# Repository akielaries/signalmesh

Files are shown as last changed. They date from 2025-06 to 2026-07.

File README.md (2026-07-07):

# signalmesh
*signalmesh* is a hybrid analog/digital synthesizer. For now it is a mess of reworked PCBs, perf/breadboards, and wires on my desk.

CAD work going on here right now: https://github.com/akielaries/signalmesh_CAD/

# Details
Don't forget to initialize submodules. ChibiOS is the RTOS used in this project on an STM32H7. I'm mostly building around an H755, 
occasionally the H753 but the H745/743 will probably work as well. AFAIK the only difference is the additional ARM M4 core and some
crypo acceleration stuff.

```
git submodule init
git submodule update
```

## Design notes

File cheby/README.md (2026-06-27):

# Cheby
These are the cheby definitions for the memory mapped address space between the
ACM (Gowin FPGA) and the APM (STM32H755)

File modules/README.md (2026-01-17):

# Modules
These are the main board components of the `signalmesh` project

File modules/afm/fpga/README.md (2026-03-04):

# Cortex M1 example
Makes use of the Tang Mega 60k and the ARM Cortex M1 softcore. It makes use of the
gwct debug module from here: https://github.com/akielaries/gwct/tree/main

Uses:
- UART1
- APB1
- DDR3
- GPIO
- SWD

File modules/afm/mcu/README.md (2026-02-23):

# Audio FX Module
The idea here is:
- To have a bunch of parallel processing in RTL on the FPGA for filters and FX
- Audio data delivery over some physical medium. ATM I'm thinking I2S
- Cortex M1 MCU  handling control via AHB registers

This project uses a Gowin GW5AST FPGA on the Tang Mega 60k and the ARM Cortex M1
softcore IP provided by Gowin. Note that any of the Gowin supported FPGAs can be
used. I used the Gowin IDE to configure all settings

# Requirements
- A Gowin supported FPGA with the ARM Cortex M1 softcore configured with:
    - UART1
    - GPIO
    - Debug (Serial Wire)
- `arm-none-eabi-gcc` toolchain
- `gdb-multiarch`
- CMake

# How to build
From the root directory:
```
cmake -S . -B build/
cmake --build build/
```
and that will produce the compile ELF under build/bin/softcore_fw_example.elf.

To load the firmware:
```
gdb-multiarch build/bin/softcore_fw_example.elf

# connect to your debugger
(gdb) target extended-remote /dev/serial/by-id/usb-Black_Magic_Debug_Black_Magic_Probe__ST-Link_v2__v2.0.0-323-gf3b99649-dirty_8A8243AE-if00
Remote debugging using /dev/serial/by-id/usb-Black_Magic_Debug_Black_Magic_Probe__ST-Link_v2__v2.0.0-323-gf3b99649-dirty_8A8243AE-if00

# scan for available SWD targets
(gdb) mon swd
Target voltage: 0.48V
Available Targets:
No. Att Driver
 1      Generic Cortex-M1 M1

# attach, load, start
(gdb) att 1
Attaching to program: /home/akiel/GMD_workspace/softcore_fw_example/build/bin/softcore_fw_example.elf, Remote target
⚠️ warning: while parsing target memory map (at line 1): Required element <memory> is missing
delay_ms (nms=50) at /home/akiel/GMD_workspace/softcore_fw_example/src/delay.c:89
89			while((temp & 0x01) && !(temp & (1 << 16)));
(gdb) load
Loading section .text, size 0x1cb4 lma 0x0
Loading section .ARM.extab, size 0x3c lma 0x1cb4
Loading section .ARM.exidx, size 0xd8 lma 0x1cf0
Loading section .data, size 0x10 lma 0x1dc8
Start address 0x000001cc, load size 7640
Transfer rate: 84 KB/sec, 694 bytes/write.
(gdb) c
Continuing.
```

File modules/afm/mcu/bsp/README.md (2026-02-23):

# Board Support Package
This code comes from the Gowin MCU Designer (GMD) tool and remains unmodified
except for the linker and startup ASM files...

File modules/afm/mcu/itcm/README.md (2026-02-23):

# Initialized ITCM
This is just the initialized ITCM (instruction tightly coupled memory)
when the Cortex M1 softcore is configured in the IP menu. In this case it just prints the uptime
in seconds and blinks some LEDs via the "RTOS" this project uses...

# Build
This initialized ITCM code is built with the same cmake invocation as the top level application

# Generate ITCM files
I'm sure this could be reverse engineered into a proper linux program but to run the Gowin
make hex util I wrap up the following in a shell script called `gowin_make_hex`:

```
#!/bin/bash

# make_hex.exe executable
MAKE_HEX_EXE="Gowin_EMPU_M1_V2.3/tool/make_hex/bin/make_hex.exe"

wine "$MAKE_HEX_EXE" "$@"
```

```
gowin_make_hex ../../build/bootloader/bin/bootloader.bin
```

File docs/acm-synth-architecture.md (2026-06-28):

# ACM Synth - Architecture

The Audio Creation Module (ACM) is a hardware polyphonic synthesizer split across
two chips:

- a **STM32H755** (Nucleo-144) as the control + I/O manager - it hosts the USB-MIDI
  keyboard, allocates voices, and streams audio out its DAC.
- an **FPGA** (Tang Nano 20K / GW2AR-18, with a Tang Primer 25K / GW5A-25 as a
  second target) as the DSP - it runs the oscillator bank that actually makes sound.

They talk over a 16-bit multiplexed **FMC** bus, with the register interface defined
once in **Cheby** and generated for both sides. The whole signal chain, top to bottom:

ACM system architecture

<sub>Diagram source: `docs/diagrams/acm-architecture.dot` - render with
`dot -Tsvg acm-architecture.dot -o acm-architecture.svg`.</sub>

## Who does what

The guiding split: the **STM32 decides what to play, the FPGA makes the sound.**
After setup, the audio samples never pass through the CPU.

| Concern | STM32H755 | FPGA |
| --- | --- | --- |
| USB-MIDI host + note parsing | yes | - |
| Voice allocation (note -> voice) | yes | - |
| Note -> pitch (tuning word) | yes | - |
| Oscillators / waveforms | - | yes (dds_synth) |
| Mixing | - | yes |
| Sample -> DAC format | - | yes (dac reg) |
| Sample streaming to DAC | DMA only (no CPU) | - |

## End-to-end: a key becomes sound

The two halves run independently - the STM32 only touches registers on note
events, the FPGA free-runs at the sample rate, and the DMA bridges them at Fs:

```mermaid
flowchart TD
    A["key pressed: note-on (note, vel)"] --> B["STM32: allocate a free voice"]
    B --> C["STM32: write voice freq + gate + level (FMC)"]
    C --> D["FPGA free-runs: phase, wave, level, mix 8 -> dac reg"]
    D --> E["TIM6 DMA: dac reg -> DAC every 48 kHz tick"]
    E --> F["key released: note-off -> clear that voice gate"]
```

## FMC register map

One flat FMC address space, decoded on the FPGA by word-address bit 6
(`core` low, `audio` high). All registers are 16-bit (the audio `freq` is 32-bit
across two words).

| FMC byte | block.register | access | meaning |
| --- | --- | --- | --- |
| 0x00 | core.magic | RO | link check, reads 0xACE1 |
| 0x02 | core.fpga_id | RO | board id (0x2018 = 20K, 0x5025 = 25K) |
| 0x04 | core.scratch | RW | scratch / LED debug |
| 0x06 | core.version | RO | gateware version |
| 0x80 | audio.ctrl | RW | engine enable, sample-rate select |
| 0x82 | audio.status | RO | active voice count |
| 0x84 | audio.sample | RO | latest mixed sample, signed (debug) |
| 0x86 | audio.dac | RO | DAC-ready 12-bit code (DMA source) |
| 0xC0 + n*8 | audio.voice[n].freq | RW | 32-bit DDS tuning word |
| 0xC4 + n*8 | audio.voice[n].ctrl | RW | gate (b0), wave (b3:1), level (b15:8) |

> Gotcha: Cheby lays a 32-bit register **big-endian** over the 16-bit bus - the
> low word address holds bits [31:16]. Matters when the STM32 writes `freq`.

## Single source of truth: Cheby

The register layout is written once as YAML and generated for both sides, so the
firmware and the gateware can never disagree on the contract.

```mermaid
flowchart TD
    Y["*.yaml (core, audio)"] --> GEN["cheby/gen.sh"]
    GEN --> OUT["C headers (STM32) + verilog (FPGA)"]
```

- `bus: wb-16` - Wishbone, 16-bit, matched to the FMC so one FMC access = one bus
  cycle, no width adapter.
- RO registers become HDL **input ports** (the design drives them, e.g. per-board
  `fpga_id`); RW registers become stored regs.

## FPGA internals

`acm_top` is a pure-wiring composition root: the FMC bridge feeds an address
decode that splits into the two register files; the audio voice registers drive
the oscillator bank, whose mixed output is converted to a DAC-ready code.
(The Fs tick divider clocks the DDS; `audio.sample` is a signed debug tap.)

```mermaid
flowchart TD
    FMC["FMC bus"] --> BR["fmc_wb_bridge"]
    BR --> DEC{"decode wb_adr[6]"}
    DEC -->|"0"| CORE["core regs"]
    DEC -->|"1"| AUDIO["audio regs"]
    AUDIO --> DDS["dds_synth 8 voices + mix"]
    DDS --> CONV[">>3 +2048, clamp"]
    CONV --> DACREG["dac reg (12-bit)"]
```

### A DDS voice

Each of the 8 voices is a numerically-controlled oscillator (the bank is
time-multiplexed: one shared sine LUT + one multiplier walk the voices each tick).
The per-voice registers `freq`, `wave`, `level`, `gate` drive each stage below:

```mermaid
flowchart TD
    ACC["phase accumulator (+= freq)"] --> SEL["select waveform (wave)"]
    SEL --> SCALE["scale by level"]
    SCALE --> GATE["apply gate"]
    GATE --> MIX["sum 8 voices / 8"]
```

- `freq` (tuning word) sets pitch: `inc = note_freq * 2^32 / Fs`, accumulated each
  sample. The STM32 builds a 128-entry MIDI-note -> tuning-word table.
- `wave` selects sine (LUT) / saw / square / triangle.
- `level` scales amplitude (driven by MIDI velocity); `gate` mutes when off.
- the mix divides by 8 for headroom, so a single voice is quiet by design.

## Audio out: STM32 stays out of the path

The FPGA produces a DAC-ready 12-bit value in `audio.dac`. TIM6 fires at Fs and
triggers a DMA that reads that one FMC register and writes the DAC - no CPU per
sample. The CPU only services USB-MIDI and voice allocation.

```mermaid
flowchart TD
    TIM["TIM6 @ 48 kHz"] --> DMA["DMA (depth-1 circular)"]
    DMA --> RD["read audio.dac (FMC)"]
    RD --> DHR["write DAC DHR12R1"]
    DHR --> PA4["PA4 -> jack -> speakers"]
```

## Testing

The RTL is verified in simulation before hardware via **cocotb** benches
(`modules/acm/acm_fpga/sim/cocotb`, run with `make <target>`):

| target | what it proves |
| --- | --- |
| `make fmc` | FMC -> bridge -> core register reads/writes |
| `make dds` | oscillator: silence / saw ramp / gate / level / mixing |
| `make acm` | full datapath: write voices over FMC, read samples + dac code back |
| `make all` | all of the above |

On-target tests live in `modules/apm/tests` (e.g. `test_fmc_core.c`,
`test_fmc_dds_e2e.c`, `test_midi_synth.c`).

## Status

```mermaid
flowchart TD
    A["USB-MIDI host"]:::done --> B["register map (Cheby)"]:::done
    B --> C["DDS voices"]:::done
    C --> D["polyphony"]:::done
    D --> E["DMA audio out"]:::done
    E --> F["envelopes / filters"]:::todo
    F --> G["custom PCB (16-bit FMC)"]:::todo

    classDef done fill:#cfc,stroke:#393;
    classDef todo fill:#eee,stroke:#999,stroke-dasharray:4;
```

Working end to end today: play the keyboard, hear polyphonic sound, with the
audio streaming itself FPGA -> DAC. Next up are per-voice envelopes / filters and
moving off the breadboard to a PCB (where 16-bit FMC is solid).

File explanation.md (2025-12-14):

You are correct to question my choice and for a good reason. However, my decision to use `i2c_bus_read_reg` and `i2c_bus_write_reg` in the refactored `ina219.c` (and `bme280.c`) instead of `i2c_master_transmit` directly was intentional and aligns with the principle of leveraging existing abstractions.

Here's why:

*   **`i2c_master_transmit`**: This is the lowest-level I2C communication function provided in `i2c.c`. It's responsible for the raw I2C transaction, including acquiring and releasing the bus, and sending/receiving bytes.
*   **`i2c_bus_read_reg` and `i2c_bus_write_reg`**: These are *higher-level convenience functions* also defined in `i2c.c` and declared in `i2c.h`. They are specifically designed for communicating with *register-based devices*. Internally, they call `i2c_master_transmit` but handle the common pattern of sending a register address byte followed by reading or writing data bytes.

By using `i2c_bus_read_reg` and `i2c_bus_write_reg`, the device drivers (`bme280.c` and `ina219.c`) focus only on the specific register addresses and data formats of their respective sensors. They don't need to re-implement the logic for sending a register address, managing the I2C bus acquisition/release, or handling generic I2C errors (which `i2c.c` already centralizes in `i2c_handle_error`).

This approach leads to:
*   **Cleaner Driver Code**: The `ina219.c` (and `bme280.c`) code is now more concise and focused on the sensor's logic.
*   **Better Modularity**: The I2C bus management and register access patterns are encapsulated in `i2c.c`, making it easier to change the underlying I2C implementation if needed without affecting the device drivers.
*   **Consistency**: All device drivers that use a register-based I2C protocol can now use these standardized `i2c_bus_read_reg` and `i2c_bus_write_reg` functions.

So, while `i2c_master_transmit` does acquire and release the bus, `i2c_bus_read_reg` and `i2c_bus_write_reg` are the more appropriate wrappers to use when dealing with register-based devices, as they provide a higher level of abstraction that is already available in your `i2c.c/h` library.

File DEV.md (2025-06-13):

- [signalmesh](#signalmesh)
- [Technical bits and features](#technical-bits-and-features)
  * [The hardware](#the-hardware)
  * [The Audio Acquisition Module (AAM)](#the-audio-acquisition-module--aam-)
  * [The Audio Creation Module (ACM)](#the-audio-creation-module--acm-)
  * [The Data Siphon Module (DSM)](#the-data-siphon-module--dsm-)
    + [Siphon](#siphon)
    + [Preset Storage](#preset-storage)
  * [The Telemetry & Debug Module (TDM)](#the-telemetry---debug-module--tdm-)
  * [The Upload and Update Module (UUM)](#the-upload-and-update-module--uum---)
  * [The infrastructure](#the-infrastructure)
    + [`mkupdater`](#-mkupdater-)
  * [Planned protocols](#planned-protocols)
  * [Planned drivers](#planned-drivers)
  * [Planned Interfaces](#planned-interfaces)
- [Incremental steps!](#incremental-steps-)
  * [UART](#uart)
  * [I2C](#i2c)
  * [USB](#usb)
  * [SPI](#spi)
  * [CAN](#can)
  * [Interrupts](#interrupts)
  * [Digital Audio Conversion](#digital-audio-conversion)
- [Some nice to haves](#some-nice-to-haves)

# signalmesh
**signalmesh** aims to be a digital synthesizer and open source
hardware/software project

# Technical bits and features
Think of this as a light requirements spec/idea list

## The hardware
* STM32H755
* STM32H753
    * ARM M7 and M4, idk how to use the M4 right now
* STM32F33
    * ARM M4. Specs say this is optimal for mixed signal work
* STM32F103
    * Cheap POS bluepill as the dev board
* GW1NR-9
    * TangNano9k as the dev board

## The Audio Acquisition Module (AAM)
* USB 3.0 MIDI input to STM32H755
* STM32H755 processes MIDI packets and sends them to a TangNano 9k FPGA
* STM32H755 delivers stereo audio data over its DAC pins to internal speakers
or to external ones if connected

## The Audio Creation Module (ACM)
* TangNano 9k FPGA acts as a synthesizer/oscillation engine
* TangNano 9k OR TangNano 1k FPGA act as an FX engine
* Output from FPGA to STM32H755 via FMC (Flexible Memory Controller)
implemented as an FPGA block/component/module. The FPGA delivers this
in a parallel fashion over several GPIO pins on the board to the
dedicated FMC pins (idk if these exist, needs research)
* I think having the FPGA deliver parallel stereo data over two GPIOs
to the H755 may be the route to take here

## The Data Siphon Module (DSM)
* This module has 2 purposes. Audio data siphoning + recording and
synth preset storage
### Siphon
* STM32H753 will listen/poll/act upon an interrupt when audio data is
delivered to a set of pins, siphoning the data from the STM32H755's
DAC. If and only if a media device is connected, otherwise this is
wasted cycles
* The siphoned data will be delivered via USB to a connected media
device (SSD, thumbdrive, etc)

### Preset Storage
Still needs more though on how all settings/parameters will be
inserted in the first place
* Record presets and save them to redundant pieces of I2C flash. Some
formatting will be needed here in the flash
* Probably some other stuff too

## The Telemetry & Debug Module (TDM)
* A STM32F33 will act as a hub for delivering all of the systems
debug messages over UART. This can get fancy and sophisticated, how can
it be made simple?
* Interfaces to various sensors for power consumption, climate data,
thermistors, some other valuable stuff idk
* Takes in that data and others like counters from various devices as
telemetry (which culd be also reported as debug messages). Ideally this
can be delivered from each board via CAN to this common module
* Failure state and telemetry should be stored in a flash device

## The Uploader and Update Module (UUM!!)
* Another STM32F103C8 that acts as a sort of simple brain for the circuit
that is responsible for orchestrating updates to other devices and itself
* This device is able to read and write to redundant flash parts
* Able to flip between firmware images and bitsreams from flash, orchesrating
what the devices down the chain should boot
* There will likely be a line like SPI to the devices down the chain but
some logic about protecting what device is written to

## The infrastructure
### `mkupdater`
`mkupdater` will be a C++ command line application that takes in a JSON
manifest file like so:

```json
{
  "acm_fpga": {
    "HWID": "ACM",
    "name": "Audio Creation Module",
    "version": "2.0.0",
    "filepath": "build/acm/acm_fpga.bin"
  },
  "acm_mcu": {
    "HWID": "ACM",
    "name": "Audio Creation Module",
    "version": "0.11.0",
    "filepath": "build/acm/acm_mcu.elf"
  },
  "dsm_mcu": {
    "HWID": "DSM",
    "name": "Data Siphon Module",
    "version": "1.2.0",
    "filepath": "build/dsm/dsm_mcu.elf"
  },
  "tdm_mcu": {
    "HWID": "TDM",
    "name": "Telemetry and Debug Module",
    "version": "0.23.1",
    "filepath": "build/tdm/tdm_mcu.elf"
  },
  "bum_mcu": {
    "HWID": "UUM",
    "name": "Uploader and Update Module",
    "version": "0.3.0",
    "filepath": "build/bum/bum_mcu.elf"
  }
}
```

From these manifest contents we should be able to create a single
binary file. This binary file will containing the code to flash
to each device in the manifest (ACM, DSM, etc). The UUM will be
responsible for parsing this blob of data and breaking it up to
be sent to each device (not sure the protocol yet, SPI is our
fastest option I think)

## Planned protocols
* UART (Universal Asynchronous Receiver-Transmitter)
* SPI (Serial Peripheral Interface)
* I2C (Inter-Intergrated circuit)
* USB (Universal Serial Bus, 2.0 and 3.0?)
* CAN (Controller Area Network)
* MIDI (Musical Instrument Digital Interface)
* FMC (Flexible Memory Controller)

Each of these will need planning around what their packets look
like

## Planned drivers
Here is a list of planned drivers needed for hardware

* 24LC256 32-kb flash (I2C)
    * `24lc256.c`
* additional RAM/memory drivers as needed
    * `<partnumber>.c`
* INA219 26V single channel DC current sensor (I2C)
    * `ina219.c`
* INA3221 26V 3-channel current sensor (I2C)
    * `ina3221.c`
* 16x02, 20x04, and or bigger displays (I2C, perhaps SPI?)
    * `1602lcd.c`, `2004lcd.c`
* LN513RA 7 segment display for counters
    * `ln513ra.c`
* BME280 temperature, humidity, pressure sensor
    * `bme280.c`
* W25Q64 QSPI flash
    * `w25q64.c`

* Network of thermistors across the board
    * `thermistor.c`

## Planned Interfaces
Backbone interfaces and code we'll need for *meshing* all of the
hardware together:

* `flash.c` - I2C and SPI flash interface. Should the FMC interface
sit in here too?
* `telemetry.c` - Telemetry interface

# Incremental steps!
* Wire up in breadboards and perfboards what I have in mind with all of the
different MCUs and FPGAs
* Create a KiCAD schematic of these connections. The PCB will come later
* Create some common code with the help of Chibi. Each MCU will
need some common code like:
    * Debug port prints via UART
    * Bootup sequences. Flash onboard+external LEDs on startup
    * and some other common functions I imagine

## UART
I sort of have this one figured out. I can send UART packets to my raspberry
pi and decode them no problem with an oscilloscope as well. This is part of
the debug print step mentioned aboved

```
sm_printf.c
```

## I2C
There are several I2C devices in the mix. Get started with a driver for each:

```
bme280.c
lcd1602.c
lcd2004.c // may not need an additional driver?
24lc256.c
ina219.c
ina3221.c
```

Most of these devices are specific to the TDM (Telemetry & Debug Module)
but the DSM (Data Siphon Module) will have a preset display and write to
a 24LC256 for the preset table

## USB
I have a micro USB pinout interface but no clue how it operates. Appears
to be a 2-pin board. I need to get an idea of what USB packets look like
and how the MIDI packets are encapsulated (I assume that's how it works).
That aside, I'm aspiring to have the following USB devices:
* Debug port - OUTPUT
* Media (maybe SD is better for this...) port - OUTPUT
* Update port - INPUT
* Maybe more?

I'm unsure of how many interfaces this will produce but I imagine it
would call the same underlying USB interface/driver...

Just getting debug print messages from 1 then all boards to a single
USB port would be sweet. Can I leverage an FTDI for this??

## SPI
I plan to store the firmware and bitstream updates in redundant SPI
flash parts. The redundancy should probably come a background task
or maybe some copy on write stuff I'm unfamiliar with. It seems like
the STM32F103 I want orchestrating all of this has two SPI interfaces
and I hope this is the case so one of them can read from flash and the
other can propogate that data to the slaves. I believe the STM32F103
in this case acts as the single *master* and the rest of the devices
are made *slaves* via the `CS` chip select pin

I think the output of this is going to be some bringup SPI code and
perhaps a driver for the 8mb W25Q64 QSPI flash. I'm really curious how
I can utilize this

```
w25q64.c
```

## CAN
I'm unfamiliar with CAN packets/frames. Will need to dig into how these
look and how I can daisy chain my TD/RD lines while decoding the data
into something sensible on the TDM (STM32F33)

Output of this is likely the beginnings of the telemtry implementation

## Interrupts
How does the STM32H7 handle interrupts? How do we implement this? There's
tons of value to these in our case and 1 of them is on update. There will
be a designated pin for signaling an update wants to take place and that
should probably have something to do with interrupts!?

## Digital Audio Conversion
The H755 should be delivering the file audio data while the H753 sniffs it
and writes that data to media (if we're recording). How can I get started
with simply generating sounds from the H755 -> some speakers

...

# Some nice to haves
* Servo motors that reset the potentiometers back to "0" on the hit
hit of a button/switch. I think this would be cool
    * Idea here could be a "third party" wire listenting in on the
    voltage output from the potentiometer and as it is listenting
    adjust it back to 0 with the servo

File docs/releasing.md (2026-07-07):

# Releasing

Releases are driven by per-module `version.yml` files, via GitHub Actions. There
is no manual tagging - you bump a version and push.

## How it works

Each releasable component owns a `version.yml` (newest entry first):

```yaml
releases:
  - version: 1.1.0
    notes:
      - what changed
  - version: 1.0.0
    notes:
      - initial release
```

The top entry's `version`:
- feeds the firmware **boot banner** (`cmake/version.cmake` reads it, then appends
  the git short hash and a `-dirty` flag), e.g. `APM v1.1.0-9d089aa8-dirty`, and
- drives the **release**: on push to `main`, `release.yml` cuts a GitHub release
  tagged `<component>/v<version>` with that entry's notes as the body.

It is idempotent: if a release for the top version already exists (e.g. you only
edited an older entry's notes), the job skips. Bump the number to cut a release.

## Components

| component  | version.yml | tag | asset(s) |
|---|---|---|---|
| apm | `modules/apm/version.yml` | `apm/v*` | `.smup` |
| bootloader | `modules/bootloader/version.yml` | `bootloader/v*` | `.hex`, `.bin` |
| acm (fpga) | `modules/acm/version.yml` | `acm/v*` | notes only (bitstream pending Gowin CI) |
| fw-tools | `tools/fw_update/version.yml`| `tools/v*` | per-platform `mkupdate-*` / `update-*` (see below) |

The bootloader release runs in the `bootloader-release` GitHub **environment** -
add required reviewers (repo Settings > Environments) so a golden-image release
needs manual approval. A check job gates it, so approval is only requested when
the bootloader version actually changed.

The demo app is built and smoke-tested in `ci.yml` but not released.

## Cut a release

1. Edit the component's `version.yml`: add a new top entry with the new version + notes.
2. Commit and push to `main`.
3. The release appears under the repo's **Releases** page with its assets attached.

## Host tools targets

`mkupdate` is portable; `update` uses Linux-only serial ioctls. The `tools`
release builds a matrix and attaches:

| asset | mkupdate | update |
|---|---|---|
| `linux-x86_64`  | yes | yes |
| `linux-aarch64` | yes (cross) | yes (cross) |
| `macos-arm64` | yes | no (Linux serial) |
| `windows-x86_64.exe` | yes | no |

Plus a `SHA256SUMS` file. Porting `update` to macOS/Windows means replacing the
`custom_baud.c` termios2 serial layer.

## Notes

- `ci.yml` builds every module on push/PR; `release.yml` only runs when a
  `version.yml` changes.
- Each `.smup` carries an image CRC and a `.sha256` published alongside.
- A `.smup` targets a bootloader speaking the `BLM1` image format - note the
  minimum bootloader version in the entry when the format changes.
- FPGA (acm) is not wired up yet - it needs a self-hosted x86-64 runner with the
  Gowin `gw_sh` toolchain, plus its own `version.yml`.
- `tools/ci/version.py` is the dependency-free reader CI uses to pull the top
  version/notes out of a `version.yml`.

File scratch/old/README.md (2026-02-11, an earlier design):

# Audio Filter Module
Uses a GW1NR-9C FPGA and the Gowin ARM Cortex M1 IP softcore

## rtl/
All RTL and IP related goodies are here

## fw/
Firmware written in C and using the arm-none-eabi-gcc toolchain

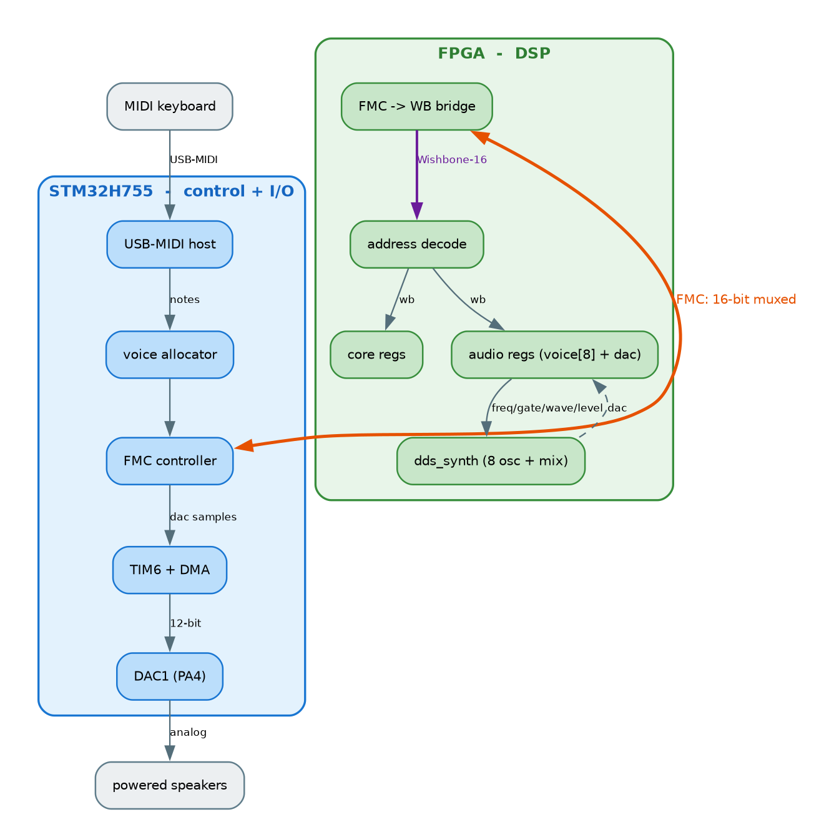
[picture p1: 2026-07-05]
docs/diagrams/acm-architecture.png

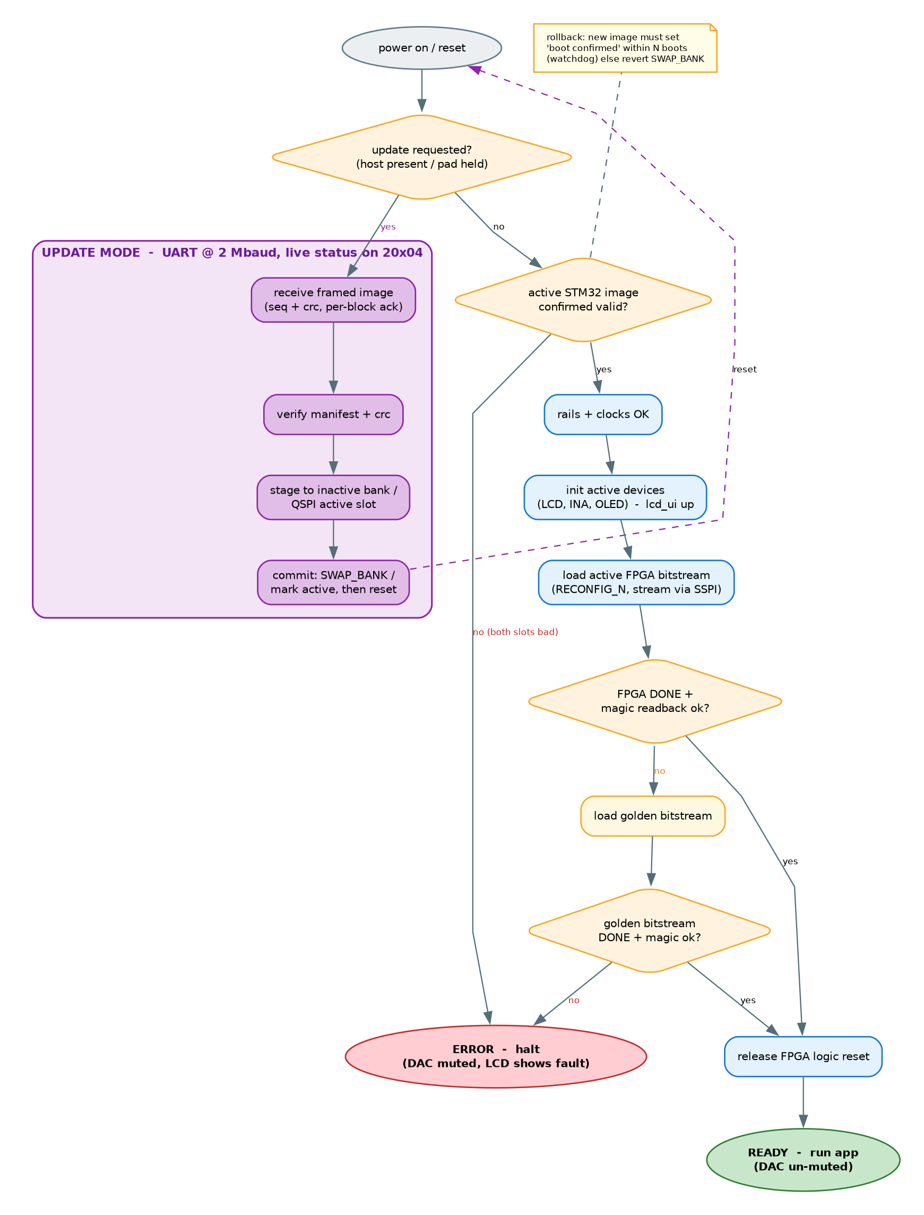
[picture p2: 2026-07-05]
docs/diagrams/boot-state-machine.png

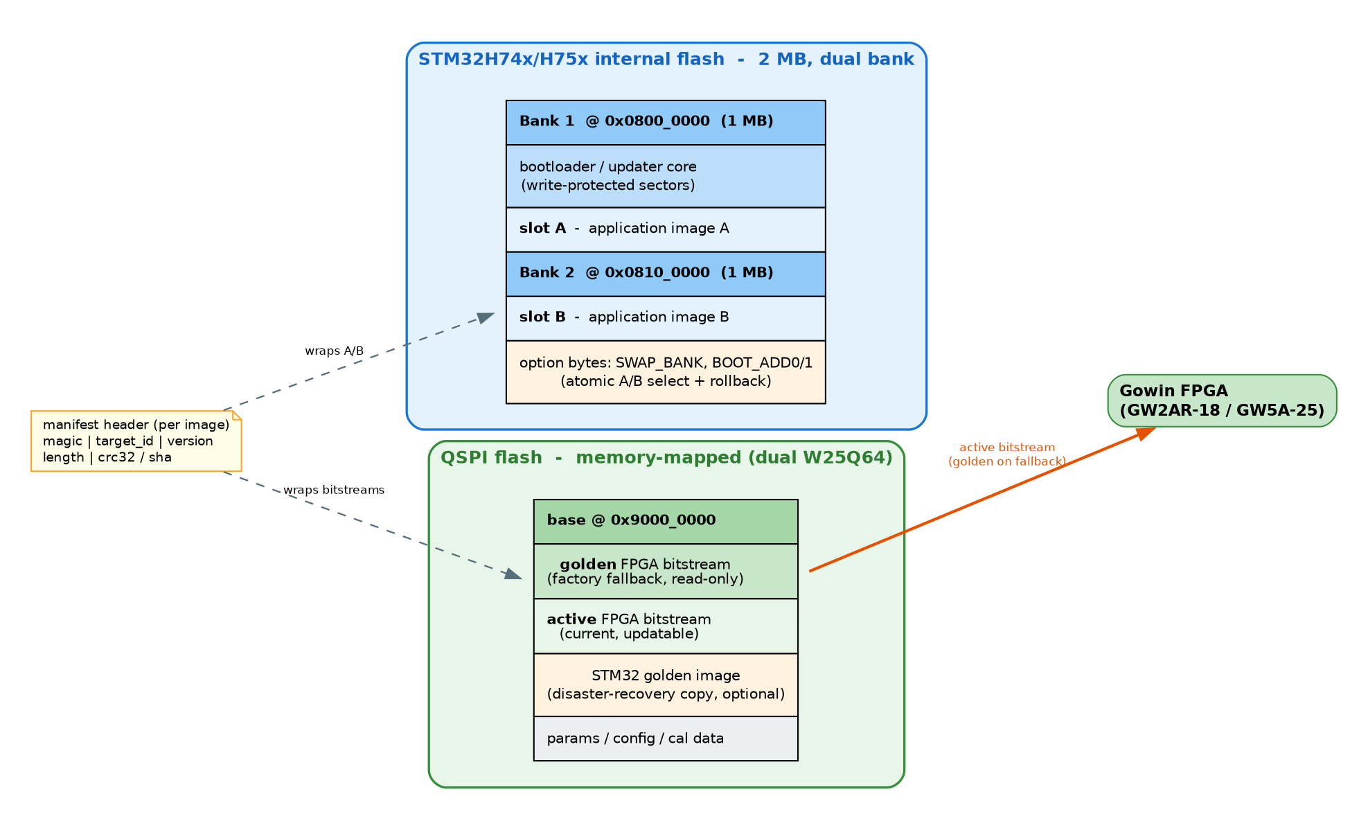
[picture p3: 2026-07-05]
docs/diagrams/boot-asset-map.png

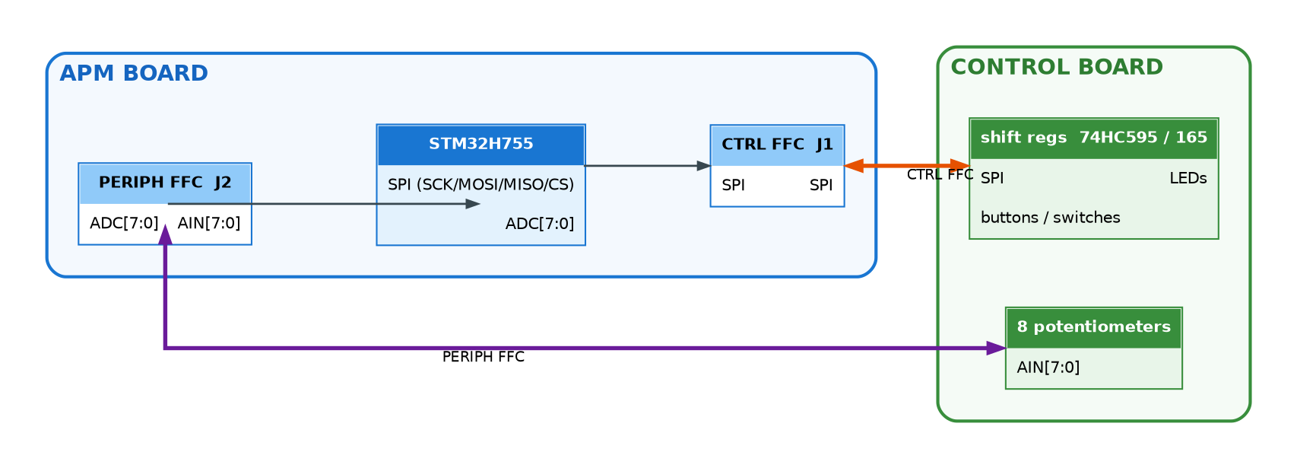
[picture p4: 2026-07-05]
docs/diagrams/apm-control-panel.png

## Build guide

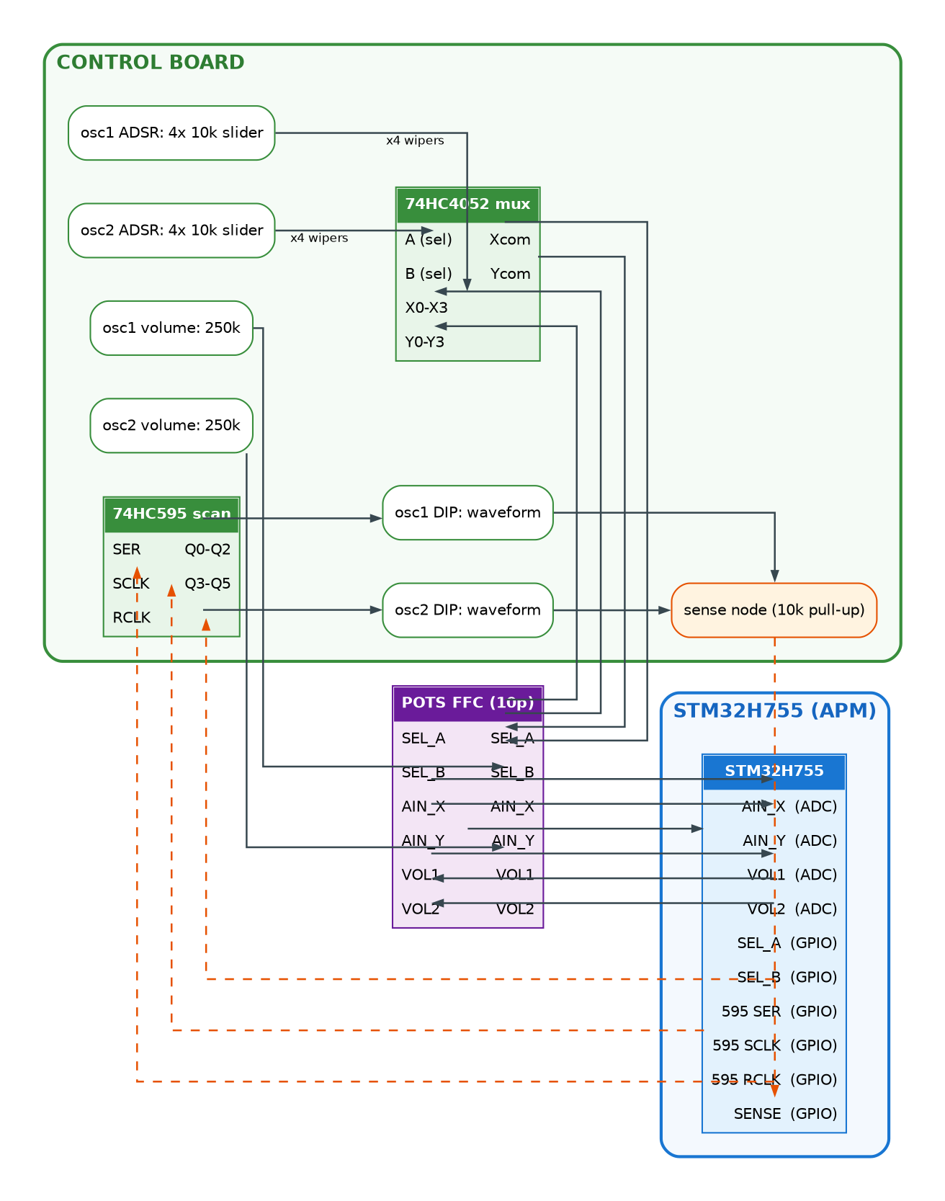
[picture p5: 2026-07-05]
docs/diagrams/control-board-wiring.png

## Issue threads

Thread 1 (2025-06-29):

plans

akielaries, 2025-06-29:
running list of things I'm thinking about

akielaries, 2025-06-29:
For recording to media, I should probably think about how complex this can really be.... I can't just overwrite the plugged in device media with audio data so there should be some supported FS I can implement

When recording data, I should name it with something like:

```
recording_<timestamp>_<sample rate?>_<bpm?>.wav
```

If I want to support some BPM based recording (which really doesn't matter tbh, the user would record this thru their DAW if they really wanted, the media piece is really just for funsies)... then I should probably add some variable metronome. There's already alot of moving parts so I prefer to defer this for now

akielaries, 2025-06-29:
# Audio Acquisition Module (AAM)
* Take in USB2.0 MIDI input
* Feed audio parameters over UART to the Audio Creation Module (ACM) to influence generated sound
* Retrieve generated sounds from the ACM FPGA via a FMMC (Flexible Memory Controller) interface
*

akielaries, 2025-06-29:
# Audio Creation Module
* Take in audio parameter data from the AAM over FMC
* Based on the parameter data, activate the desired audio engines
  * Wave engine. This/these are the generators (Oscillators). Perhaps 3 of these?
  * FX engine. A few of these for desired effects

akielaries, 2025-06-29:
# Telemetry Debug Module
* Receive telemetry info from the rest of the system via CAN
* Fill up the I2C flash in this circuit with the telemetry info to create a snapshot
* Read from a plethora of sensors placed throughout the board. Thermistors, INA power sensors, BME280 temp pressure sensor, and probably some more

This board is a bit overkill but I'm expecting to break shit as I learn PCB design and how heat transfer works in this case

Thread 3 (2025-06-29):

Potentially move FMC functionality to the DSM

akielaries, 2025-06-29:
There's like 20+ pins associated with the Flexible Memory Controller. It may be ideal for the Data Siphon Module's STM32H753 to have the connection to the FPGA via FMC + some interrupt lines (interrupt could probably be handled through the FMC established memory map instead but hooking up physical pins will help with additional debugging). This could free up the AAM (audio acquisition module doesn't quite make sense if it's not acquiring the audio anymore... audio parameter module sounds better...) to allow for more knobs and switches on the interface

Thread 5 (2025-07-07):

AFFM

akielaries, 2025-07-07:
Analog FX and Filter Module will have basically a shit ton of circuitry dedicated to common filters and FX. The input for all of these should be the two DAC pins. There should be a ON/OFF button + a two dial switch OR a three dial switch to accommodate this. The switch is for choosing the analog implementation or the digital firmware one. There should be relays that enable these respective paths. The clicking will be cool too

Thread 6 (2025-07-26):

waveform display

akielaries, 2025-07-26:
One of our devices should be able to sniff the frequencies generated over the DACs and display the waveform to an i2c or SPI display. the simple 20x4 displays I have will not suffice for this. Need better resolution and refresh

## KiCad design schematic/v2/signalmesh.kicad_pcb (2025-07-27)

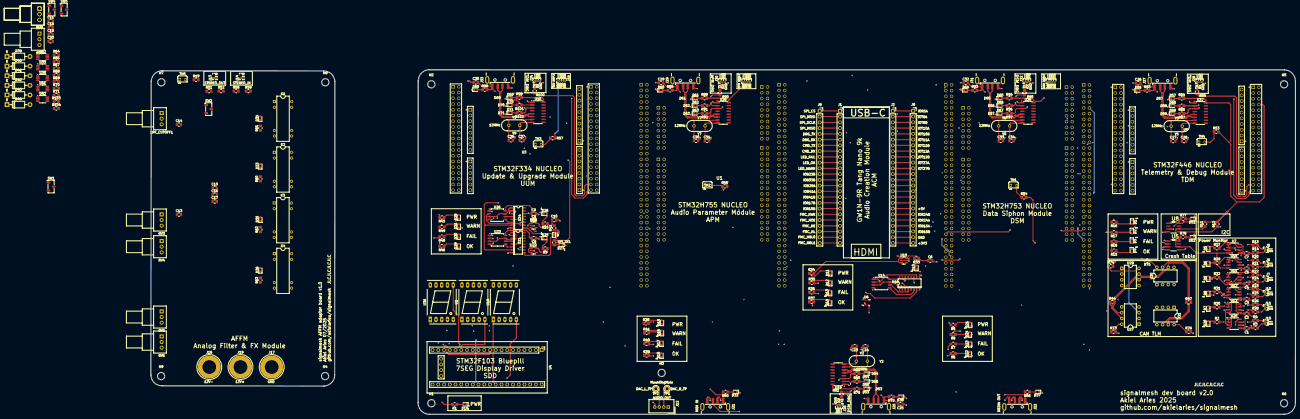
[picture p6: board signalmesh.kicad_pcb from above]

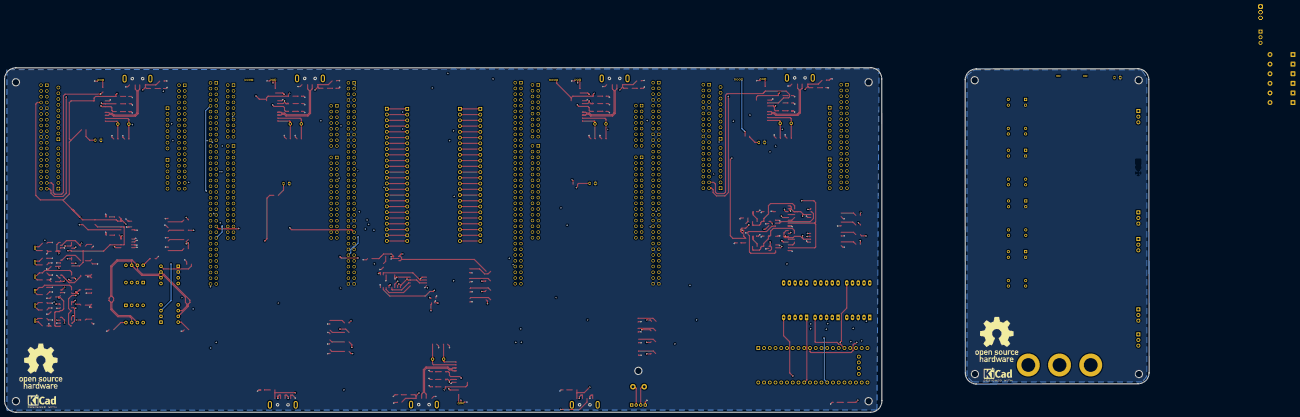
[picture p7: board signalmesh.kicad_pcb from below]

Board: 4 copper layers, 506.0 x 152.3 mm, 315 parts (4 on the bottom side), 286 nets.

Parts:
C1, C2, C3, C4, C5, C7, C10, C13, C14, C15, C16, C17: 0.1uf; C_0805_2012Metric
C6, C8, C9: 10uf; C_0805_2012Metric
C11, C20: 1uf; C_0805_2012Metric
C18, C19: 10nf; C_0805_2012Metric
C23, C24, C25, C26, C27, C28, C29, C30, C31, C32, C33, C34, C35, C36, C37: 22pf; C_0805_2012Metric
D1, D12, D16, D22, D29: LED_OK; LED_0603_1608Metric
D2, D13, D17, D23, D30: LED_FAIL; LED_0603_1608Metric
D3, D14, D18, D24, D31: LED_WARN; LED_0603_1608Metric
D4, D5, D6, D7, D8, D9, D10, D11, D15, D19, D20, D21, D25, D26, D28, D32, D37, D38, D51, D52, D53, D56, D57, D60, D61, D64, D65, D68, D69: LED_PWR; LED_0603_1608Metric
D27: SPI_SEL; LED_0603_1608Metric
D33: LPF_ON; LED_0603_1608Metric
D34: HPF_ON; LED_0603_1608Metric
D35: BPF_ON; LED_0603_1608Metric
D36: BSF_ON; LED_0603_1608Metric
D39, D40, D41, D42, D43, D44: 1N4001; D_DO-41_SOD81_P10.16mm_Horizontal
D54, D59, D63, D67, D71: RXD; LED_0603_1608Metric
D55, D58, D62, D66, D70: TXD; LED_0603_1608Metric
H1, H2, H3, H4, H5, H6, H7, H8, H9: MountingHole; MountingHole_3.2mm_M3
J1, J2, J8, J9: FPGA I/O; PinSocket_1x24_P2.54mm_Vertical
J3, J4, J18: LCD_display; PinHeader_1x04_P1.00mm_Horizontal
J5, J6, J7, J10, J11, J15: INA219_CONFIG; PinHeader_1x02_P1.00mm_Horizontal
J12: AUDIO_OUT; NS-Tech_Grove_1x04_P2mm_Vertical
J13: STEREO_OUT; PinHeader_1x02_P1.00mm_Vertical
J14: STEREO_IN; PinHeader_1x02_P1.00mm_Vertical
J16: 12V-; Banana_Jack_1Pin
J17: GND; Banana_Jack_1Pin
J19: 12V+; Banana_Jack_1Pin
J21, J22, J25, J27, J29, J31, J33: USB_A; USB_A_CNCTech_1001-011-01101_Horizontal
J26, J28, J30, J32, J34: UART_DEBUG; PinHeader_1x03_P1.00mm_Horizontal
K1, K2, K3, K4: DIPxx-1Axx-11x; Relay_StandexMeder_DIP_LowProfile
KiCAD_logo: KiCad-Logo2_5mm_SilkScreen
KiCAD_logo#2: KiCad-Logo2_5mm_SilkScreen
LPF_CUTOFF1: 100k; Potentiometer_Alps_RK09Y11_Single_Horizontal
OSHW: OSHW-Logo_19x20mm_SilkScreen
OSHW#2: OSHW-Logo_19x20mm_SilkScreen
R1, R2, R5, R6, R7, R8, R9, R10, R15, R16, R17, R18, R27, R29, R30, R31, R32, R33, R34, R35, R36, R37, R38, R39, R40, R41, R43, R45, R46, R48, R49, R50, R56, R60, R61, R62, R63, R72, R77, R78, R79, R80, R82, R83, R84, R86, R87, R88, R89, R91, R92, R93, R94, R96, R97, R98, R99, R101, R102: 300; R_0805_2012Metric_Pad1.20x1.40mm_HandSolder
R3, R4, R13, R14, R19, R20, R21, R22, R23, R24, R25, R26, R28, R53, R54, R55, R57, R64, R70, R73, R74, R75, R76: 10k; R_0805_2012Metric_Pad1.20x1.40mm_HandSolder
R11, R12: 4.7k; R_0805_2012Metric_Pad1.20x1.40mm_HandSolder
R42: 100; R_0805_2012Metric_Pad1.20x1.40mm_HandSolder
R44, R47: 120; R_0805_2012Metric_Pad1.20x1.40mm_HandSolder
R51, R52: 10K; R_0805_2012Metric_Pad1.20x1.40mm_HandSolder
R58, R59: 1K; R_0805_2012Metric_Pad1.20x1.40mm_HandSolder
R65, R71: 6k8; R_0805_2012Metric_Pad1.20x1.40mm_HandSolder
R67, R103: 200k; R_0805_2012Metric_Pad1.20x1.40mm_HandSolder
R68: 100k; R_0805_2012Metric_Pad1.20x1.40mm_HandSolder
R69: 33k; R_0805_2012Metric_Pad1.20x1.40mm_HandSolder
R81, R85, R90, R95, R100: 1k5; R_0805_2012Metric_Pad1.20x1.40mm_HandSolder
R104: 100K; R_0805_2012Metric_Pad1.20x1.40mm_HandSolder
RV3, RV4, RV5, RV6, RV7, RV8, RV9: 100k; Potentiometer_Alps_RK09Y11_Single_Horizontal
SW1: LPF_FBCK_OUT; Nidec_Copal_CAS-120A
SW2: LPF_IN_SW; Nidec_Copal_CAS-120A
SW4: LPF_OUT_SW; Nidec_Copal_CAS-120A
SW5: LPF_FBCK_IN; Nidec_Copal_CAS-120A
TH1, TH2, TH3, TH4, TH5: 10k; Heraeus_TO-92-2
TP1: DAC_R_TP; TestPoint_THTPad_D2.5mm_Drill1.2mm
TP2: DAC_L_TP; TestPoint_THTPad_D2.5mm_Drill1.2mm
U1, U17: NUCLEO-H753ZI; MODULE_NUCLEO-H753ZI
U2, U18, U36: SM420561N; 7SegmentLED_LTS6760_LTS6780
U3: NUCLEO-F303RE; ST_NUCLEO-F303RE
U4: YAAJ_BluePill_Part_Like; YAAJ_WeAct_BlackPill_SWD_2
U5, U8: 24LC256-I_SN; SOIC127P600X175-8N
U6: BME280; Bosch_LGA-8_2.5x2.5mm_P0.65mm_ClockwisePinNumbering
U7, U10, U11, U12, U13, U20: INA219AxD; SOIC-8_3.9x4.9mm_P1.27mm
U9: NUCLEO-F446RE; MODULE_NUCLEO-F446RE
U14, U23, U26: W25Q128JVS; SOIC-8_5.3x5.3mm_P1.27mm
U15, U22, U25: AP2112K-3.3; SOT-23-5
U16, U21, U24: 74HC4050D; SO16
U19, U37, U38, U39, U40: CH340G; SOIC-16_3.9x9.9mm_P1.27mm
U27, U29, U30, U31: MCP2551-I-P; DIP-8_W7.62mm
U28: 74LVC1G3157; SC70-6
U32, U33, U35, U41, U42: OPA196xDGK; VSSOP-8_3x3mm_P0.65mm
Y2, Y5, Y7, Y8, Y9: 12MHz; Crystal_HC49-4H_Vertical

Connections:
3V3_ACM: J2.24, J9.24, U14.3 (~WP/IO_{2}), U14.7 (~HOLD/~RESET/IO_{3}), U16.1 (VCC)
5V_7SDD: R1.2, U4.18 (5V), U20.8 (IN+)
5V_TDM: C1.2, C2.2, C3.2, C4.2, C5.2, C7.2, U7.5 (VS), U7.8 (IN+), U10.5 (VS), U11.5 (VS), U12.5 (VS), U13.5 (VS), U20.5 (VS)
/ACM/ACM_LED_FAIL: J1.9, J8.9, R37.2
/ACM/ACM_LED_OK: J1.10, J8.10, R35.2
/ACM/ACM_LED_WARN: J1.11, J8.11, R36.2
/ACM/ACM_SPI_CS: J1.1, J8.1, U16.3 (1A)
/ACM/ACM_SPI_MISO: J1.4, J8.4, U16.9 (4A)
/ACM/ACM_SPI_MOSI: J1.2, J8.2, U16.7 (3A)
/ACM/ACM_SPI_SCLK: J1.3, J8.3, U16.5 (2A)
/ACM_CMD_RX: J1.7, J8.7, U1.CN11_2 (PC11)
/ACM_CMD_TX: J1.8, J8.8, U1.CN11_1 (PC10)
/ACM_DBG_RX: J1.6, J8.6, J26.2, R82.1, U19.3 (RXD)
/ACM_DBG_TX: J1.5, J8.5, R80.1, R81.2, U19.2 (TXD)
/AFFM/AFFM_BPF_TOGGLE: K3.6, R62.1
/AFFM/AFFM_BSF_TOGGLE: K4.6, R63.1
/AFFM/AFFM_HPF_TOGGLE: K2.6, R60.1
/AFFM/AFFM_LPF_TOGGLE: K1.6, R61.1
/AFFM/AFFM_filters/BPF_IN: K3.1, K3.14, RV4.2
/AFFM/AFFM_filters/BPF_OUT: K3.7, K3.8
/AFFM/AFFM_filters/BSF_IN: K4.1, K4.14, RV5.2, RV6.2
/AFFM/AFFM_filters/BSF_OUT: K4.7, K4.8
/AFFM/AFFM_filters/HPF_IN: K2.1, K2.14
/AFFM/AFFM_filters/HPF_OUT: K2.7, K2.8
/AFFM/AFFM_filters/LPF_IN: K1.1, K1.14, SW4.2 (B)
/AFFM/AFFM_filters/LPF_OUT: K1.7, K1.8, R58.2, R59.2
/AFFM/AFFM_filters/LPFs/12V+: J19.1, U32.7 (V+), U33.7 (V+), U35.7 (V+), U41.7 (V+), U42.7 (V+)
/AFFM/AFFM_filters/LPFs/12V-: J17.1, U32.4 (V-), U33.4 (V-), U35.4 (V-), U41.4 (V-), U42.4 (V-)
/AFFM/AFFM_filters/LPFs/ACTIVE_LPF_OUT: C20.1, R103.2, SW4.3 (A)
/AFFM/AFFM_filters/LPFs/CFBACK_IN: D41.1 (K), D42.2 (A), R64.2, SW1.1 (C), SW5.3 (A), U33.3 (+), U33.6
/AFFM/AFFM_filters/LPFs/Fback_in: C20.2, R104.2, SW5.2 (B), U42.2 (-), U42.6
/AFFM/AFFM_filters/LPFs/PASSIVE_LPF_OUT: LPF_CUTOFF1.2, SW4.1 (C)
/AFFM/AFFM_filters/LPFs/RFBACK_OUT: R70.1, SW1.3 (A), SW5.1 (C), U35.3 (+), U35.6
/AFFM/AFFM_filters/MONO_IN: R51.2, R52.2, SW2.2 (B)
/APM/7SDD_CMD_RX: U1.CN11_63 (PG9), U4.6 (PA9)
/APM/7SDD_CMD_TX: U1.CN12_61 (PG14), U4.7 (PA10)
/APM/APM_I2C1_SCL: J4.3, U1.CN11_51 (PF1)
/APM/APM_I2C1_SDA: J4.2, U1.CN11_53 (PF0)
/APM/APM_LED_FAIL: R41.2, U1.CN12_34 (PC4)
/APM/APM_LED_OK: R39.2, U1.CN12_4 (PC6)
/APM/APM_LED_WARN: R40.2, U1.CN12_6 (PC5)
/APM/APM_USB_D+: J21.3 (D+), U1.CN12_14 (PA11)
/APM/APM_USB_D-: J21.2 (D-), U1.CN12_12 (PA12)
/APM_CAN_RD: U1.CN12_3 (PB8), U29.1 (TXD)
/APM_CAN_TD: U1.CN12_5 (PB9), U29.4 (RXD)
/APM_DAC_OUT_L: J12.2, J14.2, R51.1, TP1.1, U1.CN12_11 (PA5)
/APM_DAC_OUT_R: J12.3, J14.1, R52.1, TP2.1, U1.CN11_32 (PA4)
/APM_DBG_RX: J30.2, R92.1, U1.CN11_4 (PD2), U38.3 (RXD)
/APM_DBG_TX: R90.2, R91.1, U1.CN11_3 (PC12), U38.2 (TXD)
/CAN+: R44.1, R47.2, U27.7 (CAN+), U29.7 (CAN+), U30.7 (CAN+), U31.7 (CAN+)
/CAN-: R44.2, R47.1, U27.6 (CAN-), U29.6 (CAN-), U30.6 (CAN-), U31.6 (CAN-)
/DSM/DSM_I2C1_SCL: J3.3, U17.CN11_51 (PF1)
/DSM/DSM_I2C1_SDA: J3.2, U17.CN11_53 (PF0)
/DSM/DSM_LED_FAIL: R8.2, U17.CN12_34 (PC4)
/DSM/DSM_LED_OK: R6.2, U17.CN12_4 (PC6)
/DSM/DSM_LED_WARN: R7.2, U17.CN12_6 (PC5)
/DSM/DSM_USB_D+: J22.3 (D+), U17.CN12_14 (PA11)
/DSM/DSM_USB_D-: J22.2 (D-), U17.CN12_12 (PA12)
/DSM_CAN_RD: U17.CN12_3 (PB8), U30.1 (TXD)
/DSM_CAN_TD: U17.CN12_5 (PB9), U30.4 (RXD)
/DSM_DAC_IN_L: J13.1, R58.1, U17.CN12_11 (PA5)
/DSM_DAC_IN_R: J13.2, R59.1, U17.CN11_32 (PA4)
/DSM_DBG_RX: J32.2, R97.1, U17.CN11_4 (PD2), U39.3 (RXD)
/DSM_DBG_TX: R95.2, R96.1, U17.CN11_3 (PC12), U39.2 (TXD)
/FMC_CLK: J1.18, J8.18, U17.CN11_40 (PD3)
/FMC_D0: J2.1, J9.1, U17.CN12_46 (PD14)
/FMC_D1: J2.2, J9.2, U17.CN12_48 (PD15)
/FMC_D2: J2.3, J9.3, U17.CN11_57 (PD0)
/FMC_D3: J2.4, J9.4, U17.CN11_55 (PD1)
/FMC_D4: J2.5, J9.5, U17.CN12_44 (PE7)
/FMC_D5: J2.6, J9.6, U17.CN12_40 (PE8)
/FMC_D6: J2.7, J9.7, U17.CN12_52 (PE9)
/FMC_D7: J2.8, J9.8, U17.CN12_47 (PE10)
/FMC_D8: J2.9, J9.9, U17.CN12_56 (PE11)
/FMC_D9: J2.10, J9.10, U17.CN12_49 (PE12)
/FMC_D10: J2.11, J9.11, U17.CN12_55 (PE13)
/FMC_D11: J2.12, J9.12, U17.CN12_51 (PE14)
/FMC_D12: J2.13, J9.13, U17.CN12_53 (PE15)
/FMC_D13: J2.14, J9.14, U17.CN12_10 (PD8)
/FMC_D14: J2.15, J9.15, U17.CN11_69 (PD9)
/FMC_D15: J2.16, J9.16, U17.CN12_65 (PD10)
/FMC_NBL0: J1.23, J8.23, U17.CN12_64 (PE0)
/FMC_NBL1: J1.24, J8.24, U17.CN11_61 (PE1)
/FMC_NE: J1.21, J8.21, U17.CN12_19 (PC7)
/FMC_NL: J1.22, J8.22, U17.CN11_21 (PB7)
/FMC_NOE: J1.20, J8.20, U17.CN11_39 (PD4)
/FMC_NWE: J1.19, J8.19, U17.CN11_41 (PD5)
/IRQ0: U1.CN11_62 (PE6), U17.CN11_47 (PE3)
/ISR0: U1.CN11_47 (PE3), U17.CN11_62 (PE6)
/TDM/7SDD_VDD: R2.2, U20.7 (IN-)
/TDM/ACM_VDD: R29.2, U10.7 (IN-)
/TDM/APM_VDD: R30.2, U13.7 (IN-)
/TDM/DSM_VDD: R32.2, U11.7 (IN-)
/TDM/TDM_I2C1_SCL: J18.3, R11.1, U5.6 (SCL), U6.4 (SCK), U7.4 (SCL), U8.6 (SCL), U9.CN10_3 (PB8), U10.4 (SCL), U11.4 (SCL), U12.4 (SCL), U13.4 (SCL), U20.4 (SCL)
/TDM/TDM_I2C1_SDA: J18.2, R12.1, U5.5 (SDA), U6.5 (SDO), U7.3 (SDA), U8.5 (SDA), U9.CN10_5 (PB9), U10.3 (SDA), U11.3 (SDA), U12.3 (SDA), U13.3 (SDA), U20.3 (SDA)
/TDM/TDM_LED_FAIL: R18.2, U9.CN10_6 (PC5)
/TDM/TDM_LED_OK: R16.2, U9.CN10_11 (PA5)
/TDM/TDM_LED_WARN: R17.2, U9.CN10_34 (PC4)
/TDM/UUM_VDD: R31.2, U12.7 (IN-)
/TDM_CAN_RD: U9.CN10_14 (PA11), U31.1 (TXD)
/TDM_CAN_TD: U9.CN10_12 (PA12), U31.4 (RXD)
/TDM_DBG_RX: J28.2, R87.1, U9.CN10_37 (PA3), U37.3 (RXD)
/TDM_DBG_TX: R85.2, R86.1, U9.CN10_35 (PA2), U37.2 (TXD)
/USB_debug_ACM/D+: J25.3 (D+), U19.5 (UD+)
/USB_debug_ACM/D-: J25.2 (D-), U19.6 (UD-)
/USB_debug_ACM/DBG_TX: J26.1, R81.1
/USB_debug_APM/D+: J29.3 (D+), U38.5 (UD+)
/USB_debug_APM/D-: J29.2 (D-), U38.6 (UD-)
/USB_debug_APM/DBG_TX: J30.1, R90.1
/USB_debug_DSM/D+: J31.3 (D+), U39.5 (UD+)
/USB_debug_DSM/D-: J31.2 (D-), U39.6 (UD-)
/USB_debug_DSM/DBG_TX: J32.1, R95.1
/USB_debug_TDM/D+: J27.3 (D+), U37.5 (UD+)
/USB_debug_TDM/D-: J27.2 (D-), U37.6 (UD-)
/USB_debug_TDM/DBG_TX: J28.1, R85.1
/USB_debug_UUM/D+: J33.3 (D+), U40.5 (UD+)
/USB_debug_UUM/D-: J33.2 (D-), U40.6 (UD-)
/USB_debug_UUM/DBG_TX: J34.1, R100.1
/UUM/UUM_LED_FAIL: R49.2, U3.CN7_38 (PC0)
/UUM/UUM_LED_OK: R46.2, U3.CN7_35 (PC2)
/UUM/UUM_LED_WARN: R48.2, U3.CN7_36 (PC1)
/UUM/UUM_SPI1_CS: U3.CN10_23 (PA8), U21.3 (1A)
/UUM/UUM_SPI1_MISO: U3.CN10_13 (PA6), U28.6
/UUM/UUM_SPI1_MOSI: U3.CN10_15 (PA7), U21.7 (3A), U24.7 (3A)
/UUM/UUM_SPI1_SCLK: U3.CN10_11 (PA5), U21.5 (2A), U24.5 (2A)
/UUM/UUM_SPI2_CS: U3.CN10_21 (PA9), U24.3 (1A)
/UUM/UUM_SPI_SEL: R43.1, U3.CN7_25 (PC14), U28.4
/UUM/UUM_spiflash/UUM_SPI1_MISO_A: U21.9 (4A), U28.3
/UUM/UUM_spiflash/UUM_SPI1_MISO_B: U24.9 (4A), U28.1
/UUM_CAN_RD: U3.CN10_3 (PB8), U27.1 (TXD)
/UUM_CAN_TD: U3.CN10_5 (PB9), U27.4 (RXD)
/UUM_DBG_RX: J34.2, R102.1, U3.CN10_37 (PA3), U40.3 (RXD)
/UUM_DBG_TX: R100.2, R101.1, U3.CN10_35 (PA2), U40.2 (TXD)
ACM_VDD: C25.2, J2.18, J9.18, J25.1 (VBUS), R34.2, R72.2, R79.2, U15.1 (VIN), U15.3 (EN), U19.16 (VCC)
APM_VDD: C29.2, J4.1, J21.1 (VBUS), J29.1 (VBUS), R38.2, R50.2, R88.2, R89.2, U1.CN11_18 (5V), U29.3 (VDD), U38.16 (VCC)
DSM_VDD: C32.2, J3.1, J22.1 (VBUS), J31.1 (VBUS), R5.2, R56.2, R93.2, R94.2, U17.CN11_18 (5V), U30.3 (VDD), U39.16 (VCC)
GND: C1.1, C2.1, C3.1, C4.1, C5.1, C6.2, C7.1, C8.2, C9.2, C10.2, C14.1, C15.1, C17.1, C19.2, C23.2, C24.2, C25.1, C26.1, C27.2, C28.2, C29.1, C30.2, C31.2, C32.1, C33.2, C34.2, C35.1, C36.2, C37.2, D1.1 (K), D2.1 (K), D3.1 (K), D4.1 (K), D5.1 (K), D6.1 (K), D7.1 (K), D8.1 (K), D9.1 (K), D10.1 (K), D11.1 (K), D12.1 (K), D13.1 (K), D14.1 (K), D15.1 (K), D16.1 (K), D17.1 (K), D18.1 (K), D19.1 (K), D20.1 (K), D21.1 (K), D22.1 (K), D23.1 (K), D24.1 (K), D25.1 (K), D26.1 (K), D27.1 (K), D28.1 (K), D29.1 (K), D30.1 (K), D31.1 (K), D32.1 (K), D33.1 (K), D34.1 (K), D35.1 (K), D36.1 (K), D37.1 (K), D38.1 (K), D51.1 (K), D52.1 (K), D53.1 (K), D54.1 (K), D55.1 (K), D56.1 (K), D57.1 (K), D58.1 (K), D59.1 (K), D60.1 (K), D61.1 (K), D62.1 (K), D63.1 (K), D64.1 (K), D65.1 (K), D66.1 (K), D67.1 (K), D68.1 (K), D69.1 (K), D70.1 (K), D71.1 (K), J2.23, J3.4, J4.4, J9.23, J12.4, J18.4, J21.4 (GND), J22.4 (GND), J25.4 (GND), J26.3, J27.4 (GND), J28.3, J29.4 (GND), J30.3, J31.4 (GND), J32.3, J33.4 (GND), J34.3, K1.2, K2.2, K3.2, K4.2, R3.1, R4.1, R13.1, R14.1, R20.1, R21.1, R22.1, R23.1, R24.1, R25.1, R26.1, R28.1, R65.1, R67.1, R69.1, R71.1, R73.2, R74.2, R75.2, R76.2, R103.1, R104.1, RV3.3, RV5.3, TH1.1, TH2.1, TH3.1, TH4.1, TH5.1, U1.CN11_8 (GND_CN11), U1.CN11_19 (GND_CN11), U1.CN11_20 (GND_CN11), U1.CN11_22 (GND_CN11), U1.CN11_49 (GND_CN11), U1.CN11_60 (GND_CN11), U1.CN11_71 (GND_CN11), U1.CN11_72 (GND_CN11), U2.3 (CC), U2.8 (CC), U3.CN10_9 (GND_S2), U3.CN10_20 (GND_S2), U4.39 (GND), U5.1 (A0), U5.2 (A1), U5.3 (A2), U5.4 (VSS), U6.1 (GND), U6.7 (GND), U7.6 (GND), U8.1 (A0), U8.3 (A2), U8.4 (VSS), U9.CN10_9 (CN10_GND), U9.CN10_20 (CN10_GND), U10.6 (GND), U11.6 (GND), U12.6 (GND), U13.6 (GND), U14.4 (GND), U15.2 (GND), U16.8 (GND), U16.11 (5A), U16.14 (6A), U17.CN11_8 (GND_CN11), U17.CN11_19 (GND_CN11), U17.CN11_20 (GND_CN11), U17.CN11_22 (GND_CN11), U17.CN11_49 (GND_CN11), U17.CN11_60 (GND_CN11), U17.CN11_71 (GND_CN11), U17.CN11_72 (GND_CN11), U18.3 (CC), U18.8 (CC), U19.1 (GND), U20.6 (GND), U21.8 (GND), U21.11 (5A), U21.14 (6A), U22.2 (GND), U23.4 (GND), U24.8 (GND), U24.11 (5A), U24.14 (6A), U25.2 (GND), U26.4 (GND), U27.2 (VSS), U28.2 (GND), U29.2 (VSS), U30.2 (VSS), U31.2 (VSS), U36.3 (CC), U36.8 (CC), U37.1 (GND), U38.1 (GND), U39.1 (GND), U40.1 (GND)
unnamed: C10.1, R42.2
unnamed: C11.1, R67.2, R68.2, RV9.1
unnamed: C13.1, RV3.1
unnamed: C14.2, LPF_CUTOFF1.3
unnamed: C15.2, RV4.3
unnamed: C16.1, RV5.1
unnamed: C16.2, RV6.1
unnamed: C17.2, RV6.3
unnamed: D1.2 (A), R16.1
unnamed: D2.2 (A), R17.1
unnamed: D3.2 (A), R18.1
unnamed: D4.2 (A), R15.1
unnamed: D5.2 (A), R27.1
unnamed: D6.2 (A), R29.1
unnamed: D7.2 (A), R30.1
unnamed: D8.2 (A), R31.1
unnamed: D9.2 (A), R32.1
unnamed: D10.2 (A), R33.2
unnamed: D11.2 (A), R34.1
unnamed: D12.2 (A), R35.1
unnamed: D13.2 (A), R36.1
unnamed: D14.2 (A), R37.1
unnamed: D15.2 (A), R38.1
unnamed: D16.2 (A), R39.1
unnamed: D17.2 (A), R40.1
unnamed: D18.2 (A), R41.1
unnamed: D19.2 (A), R1.1
unnamed: D20.2 (A), R2.1
unnamed: D21.2 (A), R5.1
unnamed: D22.2 (A), R6.1
unnamed: D23.2 (A), R7.1
unnamed: D24.2 (A), R8.1
unnamed: D25.2 (A), R9.2
unnamed: D26.2 (A), R10.2
unnamed: D27.2 (A), R43.2
unnamed: D28.2 (A), R45.1
unnamed: D29.2 (A), R46.1
unnamed: D30.2 (A), R48.1
unnamed: D31.2 (A), R49.1
unnamed: D32.2 (A), R50.1
unnamed: D33.2 (A), R61.2
unnamed: D34.2 (A), R60.2
unnamed: D35.2 (A), R62.2
unnamed: D36.2 (A), R63.2
unnamed: D37.2 (A), R56.1
unnamed: D38.2 (A), R72.1
unnamed: D39.2 (A), D44.1 (K), R64.1, R65.2, U33.2 (-)
unnamed: D39.1 (K), D40.2 (A)
unnamed: D40.1 (K), D41.2 (A)
unnamed: D42.1 (K), D43.2 (A)
unnamed: D43.1 (K), D44.2 (A)
unnamed: D51.2 (A), R77.2
unnamed: D52.2 (A), R78.2
unnamed: D53.2 (A), R79.1
unnamed: D54.2 (A), R82.2
unnamed: D55.2 (A), R80.2
unnamed: D56.2 (A), R83.1
unnamed: D57.2 (A), R84.1
unnamed: D58.2 (A), R86.2
unnamed: D59.2 (A), R87.2
unnamed: D60.2 (A), R88.1
unnamed: D61.2 (A), R89.1
unnamed: D62.2 (A), R91.2
unnamed: D63.2 (A), R92.2
unnamed: D64.2 (A), R93.1
unnamed: D65.2 (A), R94.1
unnamed: D66.2 (A), R96.2
unnamed: D67.2 (A), R97.2
unnamed: D68.2 (A), R98.1
unnamed: D69.2 (A), R99.1
unnamed: D70.2 (A), R101.2
unnamed: D71.2 (A), R102.2
unnamed: J5.1, J5.2, R13.2, R14.2, U7.1 (A1), U7.2 (A0)
unnamed: J6.1, J6.2, R20.2, R21.2, U10.1 (A1), U10.2 (A0)
unnamed: J7.1, J7.2, R22.2, R24.2, U11.1 (A1), U11.2 (A0)
unnamed: J10.1, J10.2, R23.2, R25.2, U12.1 (A1), U12.2 (A0)
unnamed: J11.1, J11.2, R26.2, R28.2, U13.1 (A1), U13.2 (A0)
unnamed: J15.1, J15.2, R3.2, R4.2, U20.1 (A1), U20.2 (A0)
unnamed: R19.1, TH5.2
unnamed: RV3.2, RV4.1
unnamed: C18.2, SW1.2 (B)
unnamed: LPF_CUTOFF1.1, SW2.3 (A)
unnamed: C11.2, SW2.1 (C)
unnamed: U2.7 (A), U4.28 (PA3)
unnamed: U2.6 (B), U4.27 (PA2)
unnamed: U2.4 (C), U4.26 (PA1)
unnamed: U2.2 (D), U4.25 (PA0)
unnamed: U2.5 (DP), U4.16 (PB8)
unnamed: U2.1 (E), U4.24 (PC15)
unnamed: U2.9 (F), U4.23 (PC14)
unnamed: U2.10 (G), U4.17 (PB9)
unnamed: R57.1, TH3.2, U9.CN7_32 (PA4)
unnamed: R55.1, TH2.2, U9.CN7_34 (PB0)
unnamed: R54.1, TH1.2, U9.CN7_38 (PC0/PB8)
unnamed: R53.1, TH4.2, U9.CN7_36 (PC1/PB9)
unnamed: U14.6 (CLK), U16.4 (2Y)
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

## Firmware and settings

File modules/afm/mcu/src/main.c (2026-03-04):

#include "GOWIN_M1.h"

#include "kernel.h"
#include "debug.h"
#include "gpio.h"
#include "delay.h"
#include "sys_defs.h"
#include "GOWIN_M1_ddr3.h"

#include "hw.h"

#include <stdint.h>


// dummy generator
static uint32_t lcg_state = 12345;

static uint32_t lcg_rand(void) {
  lcg_state = lcg_state * 1664525 + 1013904223;
  return lcg_state;
}

/* ========================================================= */

// IDLE THREAD! this should ideally just be main() i think but idk
THREAD_STACK(idle, 256);
THREAD_FUNCTION(idle_fn, arg) {
  while (1) {
    __WFI();
  }
}

THREAD_STACK(uptime, 512);
THREAD_FUNCTION(uptime_fn, arg) {
  while (1) {
    dbg_printf("uptime: %ds\r\n", system_time_ms / 1000);
    thread_sleep_ms(1000);
  }
}

THREAD_STACK(blink1_thd, 512);
THREAD_FUNCTION(blink1_fn, arg) {
  while (1) {
    dbg_printf("pin0\r\n");
    GPIO_ToggleBit(GPIO0, GPIO_Pin_0);
    thread_sleep_ms(500);
  }
}

THREAD_STACK(blink2_thd, 512);
THREAD_FUNCTION(blink2_fn, arg) {
  while (1) {
    dbg_printf("pin1\r\n");
    GPIO_ToggleBit(GPIO0, GPIO_Pin_1);
    thread_sleep_ms(1000);
  }
}

THREAD_STACK(fast_thd, 256);
THREAD_FUNCTION(fast_fn, arg) {
  while (1) {
    GPIO_ToggleBit(GPIO0, GPIO_Pin_2);
    // thread_sleep_ms(2);
  }
}

// basic thread that just yields
// some CPU heavy task that will spit out the result every few seconds or
// something related
THREAD_STACK(compute_thd, 512);
THREAD_FUNCTION(compute_fn, arg) {
  while (1) {
    uint32_t iters  = 500000 + (lcg_rand() % 5000000);
    uint32_t result = 0;

    uint32_t t_start = system_time_ms;

    for (uint32_t i = 0; i < iters; i++) {
      result += i * i;
      if ((i % 1000) == 0)
        thread_yield(); // could remove this manual yield
    }

    uint32_t elapsed = system_time_ms - t_start;
    dbg_printf("compute result: %u, took %d ms (%d iters)\r\n", result, elapsed, iters);
  }
}

void ddr3_pattern_test(void) {
  dbg_printf("\r\n=== DDR3 Pattern Test ===\r\n");

  uint32_t errors = 0;

  // Make buffers static to avoid stack issues
  static uint32_t write_buf[4];
  static uint32_t read_buf[4];

  // Write pattern to 64 different 16-byte blocks (1KB total)
  dbg_printf("Writing pattern to 64 blocks (1KB)...\r\n");
  for (uint32_t block = 0; block < 64; block++) {
    // Fill buffer with pattern
    write_buf[0] = (block * 4) + 0;
    write_buf[1] = (block * 4) + 1;
    write_buf[2] = (block * 4) + 2;
    write_buf[3] = (block * 4) + 3;

    uint32_t addr = block * 16; // 16-byte aligned addresses
    DDR3_Write(DDR3_BASE + addr, write_buf);

    if ((block % 16) == 0) {
      dbg_printf("  Written %d blocks...\r\n", block);
    }
  }

  dbg_printf("Reading back and verifying...\r\n");
  for (uint32_t block = 0; block < 64; block++) {
    uint32_t addr = block * 16;
    DDR3_Read(DDR3_BASE + addr, read_buf);

    // Verify each word in the block
    for (int word = 0; word < 4; word++) {
      uint32_t expected = (block * 4) + word;
      if (read_buf[word] != expected) {
        dbg_printf("  ERROR at addr 0x%08X[%d]: expected 0x%08X, read 0x%08X\r\n",
                   DDR3_BASE + addr,
                   word,
                   expected,
                   read_buf[word]);
        errors++;
        if (errors > 10)
          goto done;
      }
    }

    if ((block % 16) == 0) {
      dbg_printf("  Verified %d blocks...\r\n", block);
    }
  }

done:
  if (errors == 0) {
    dbg_printf("PASS: Pattern test succeeded! All 256 words correct.\r\n");
  } else {
    dbg_printf("FAIL: Pattern test failed with %d errors\r\n", errors);
  }

  // Show first 4 blocks (64 bytes = 16 words)
  dbg_printf("\r\nFirst 4 blocks at DDR3_BASE:\r\n");
  for (uint32_t block = 0; block < 4; block++) {
    DDR3_Read(DDR3_BASE + (block * 16), read_buf);
    dbg_printf("  Block %d [0x%08X]: 0x%08X 0x%08X 0x%08X 0x%08X\r\n",
               block,
               DDR3_BASE + (block * 16),
               read_buf[0],
               read_buf[1],
               read_buf[2],
               read_buf[3]);
  }
}

void ddr3_rw_test(void) {
  dbg_printf("DDR3 test (16-byte aligned)\r\n");

  static uint32_t write_data[6][4] = {{0x91234567, 0x89abcdef, 0xfedcba98, 0x76543210},
                                      {0x66666666, 0x88888888, 0xeeeeeeee, 0xffffffff},
                                      {1, 2, 3, 4},
                                      {5, 6, 7, 8},
                                      {9, 10, 11, 12},
                                      {13, 14, 15, 16}};

  static uint32_t read_data[6][4];

  unsigned int addr = 0x00;

  dbg_printf("Writing 6 blocks with 16-byte increment...\r\n");
  for (int i = 0; i < 6; i++) {
    DDR3_Write(addr + i * 16, write_data[i]); // Changed to i*16
  }

  dbg_printf("Reading back...\r\n");
  for (int i = 0; i < 6; i++) {
    DDR3_Read(addr + i * 16, read_data[i]); // Changed to i*16
  }

  dbg_printf("Results:\r\n");
  for (int i = 0; i < 6; i++) {
    dbg_printf("Block %d: 0x%08X 0x%08X 0x%08X 0x%08X ",
               i,
               read_data[i][0],
               read_data[i][1],
               read_data[i][2],
               read_data[i][3]);

    // Check if correct
    if (read_data[i][0] == write_data[i][0] && read_data[i][1] == write_data[i][1] &&
        read_data[i][2] == write_data[i][2] && read_data[i][3] == write_data[i][3]) {
      dbg_printf("OK\r\n");
    } else {
      dbg_printf("MISMATCH\r\n");
    }
  }
}

/* ========================== MAIN ========================= */
/* ========================================================= */
/*
 * this is the main entry point for the application. it initializes the system and the threads
 */
int main(void) {
  hw_init();

  dbg_printf("DDR3 init\r\n");
  uint8_t status = DDR3_Init();
  dbg_printf("DDR3 init status: %d\r\n", status);

  ddr3_rw_test();
  // ddr3_pattern_test();

  // start the scheduler/kernel
  dbg_printf("initializing kernel...\r\n");
  kernel_init();

  dbg_printf("creating threads...\r\n");

  // idle thread with lowest priority
  mkthd_static(idle, idle_fn, sizeof(idle), PRIO_LOW, NULL);
  mkthd_static(uptime, uptime_fn, sizeof(uptime), PRIO_NORMAL, NULL);

  mkthd_static(blink1_thd, blink1_fn, sizeof(blink1_thd), PRIO_NORMAL, NULL);
  mkthd_static(blink2_thd, blink2_fn, sizeof(blink2_thd), PRIO_NORMAL, NULL);

  mkthd_static(fast_thd, fast_fn, sizeof(fast_thd), PRIO_LOW, NULL);
  mkthd_static(compute_thd, compute_fn, sizeof(compute_thd), PRIO_LOW, NULL);


  dbg_printf("system_time_ms before start: %d\r\n", system_time_ms);

  dbg_printf("starting kernel...\r\n");
  kernel_start();

  dbg_printf("main loop...\r\n");
  while (1) {
    thread_sleep_ms(100);
  }
  return 0;
}

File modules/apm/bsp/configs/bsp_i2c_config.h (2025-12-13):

#pragma once

#include "hal.h"

// Define GPIO pins for I2C2 on PF0/PF1
#define BSP_I2C2_SCL_PORT GPIOF
#define BSP_I2C2_SCL_PIN  1
#define BSP_I2C2_SDA_PORT GPIOF
#define BSP_I2C2_SDA_PIN  0
#define BSP_I2C2_AF       4 // Alternate Function for I2C2

// Extern declarations for the I2CConfig and I2CDriver instance
extern const I2CConfig bsp_i2c_config;
extern I2CDriver *const bsp_i2c_driver;

void bsp_i2c_init(void);

// Convenience macros for GPIO pins
#define bsp_i2c_scl_port BSP_I2C2_SCL_PORT
#define bsp_i2c_scl_pin  BSP_I2C2_SCL_PIN
#define bsp_i2c_sda_port BSP_I2C2_SDA_PORT
#define bsp_i2c_sda_pin  BSP_I2C2_SDA_PIN
#define bsp_i2c_af       BSP_I2C2_AF

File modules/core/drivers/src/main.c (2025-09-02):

/**
 * signalmesh 2025
 *
 * @file
 * @brief testing some H755 code
 * @author Akiel Aries
 */

#include "ch.h"
#include "chprintf.h"

#include "hal.h"
#include "rt_test_root.h"
#include "oslib_test_root.h"


static SerialConfig const uart5_cfg = {
  //.speed = 115200,
  .speed = 1000000,
  .cr1   = 0,
  .cr2   = USART_CR2_STOP1_BITS,
  .cr3   = 0,
};

/*
 * This is a periodic thread that does absolutely nothing except flashing
 * a LED.
 */
static THD_WORKING_AREA(waThread1, 128);
static THD_FUNCTION(Thread1, arg) {
  palSetPadMode(GPIOA, GPIOA_PIN3, PAL_STM32_MODE_OUTPUT);
  palSetPadMode(GPIOC, GPIOC_PIN0, PAL_STM32_MODE_OUTPUT);
  palSetPadMode(GPIOC, GPIOC_PIN3, PAL_STM32_MODE_OUTPUT);

  (void)arg;
  chRegSetThreadName("blinker");
  while (true) {
    // set
    palSetLine(LINE_LED1);
    chThdSleepMilliseconds(200);
    palSetLine(LINE_LED2);
    chThdSleepMilliseconds(200);
    palSetLine(LINE_LED3);
    chThdSleepMilliseconds(200);

    palSetPad(GPIOA, GPIOA_PIN3);
    chThdSleepMilliseconds(200);
    palSetPad(GPIOC, GPIOC_PIN0);
    chThdSleepMilliseconds(200);
    palSetPad(GPIOC, GPIOC_PIN3);
    chThdSleepMilliseconds(200);

    // clear
    palClearLine(LINE_LED1);
    chThdSleepMilliseconds(200);
    palClearLine(LINE_LED2);
    chThdSleepMilliseconds(200);
    palClearLine(LINE_LED3);
    chThdSleepMilliseconds(200);

    palClearPad(GPIOA, GPIOA_PIN3);
    chThdSleepMilliseconds(200);
    palClearPad(GPIOC, GPIOC_PIN0);
    chThdSleepMilliseconds(200);
    palClearPad(GPIOC, GPIOC_PIN3);
    chThdSleepMilliseconds(200);
  }
}

/*
 * Application entry point.
 */
int main(void) {

  /*
   * System initializations.
   * - HAL initialization, this also initializes the configured device drivers
   *   and performs the board-specific initializations.
   * - Kernel initialization, the main() function becomes a thread and the
   *   RTOS is active.
   */
  halInit();
  chSysInit();

  /*
   * Activates the serial driver 1 using the driver default configuration.
   */
  palSetPadMode(GPIOC, GPIOC_PIN12, PAL_MODE_ALTERNATE(8)); // TX
  palSetPadMode(GPIOD, GPIOD_PIN2, PAL_MODE_ALTERNATE(8));  // RX
  palSetPadMode(GPIOG, GPIOG_PIN3, PAL_MODE_INPUT);         // ext push button
  palSetPadMode(GPIOA, GPIOA_PIN3, PAL_STM32_MODE_OUTPUT);  // blue LED?

  sdStart(&SD3, NULL);
  sdStart(&SD5, &uart5_cfg);
  BaseSequentialStream *chp = (BaseSequentialStream *)&SD5;

  chprintf(chp, "start of program...\r\n");
  // flash some leds to signal the start
  for (uint8_t i = 0; i < 10; i++) {
    palSetPad(GPIOA, GPIOA_PIN3);
    chThdSleepMilliseconds(50);
    palClearPad(GPIOA, GPIOA_PIN3);
    chThdSleepMilliseconds(50);
  }

  /*
   * Creates the example thread.
   */
  chThdCreateStatic(waThread1,
                    sizeof(waThread1),
                    NORMALPRIO + 1,
                    Thread1,
                    NULL);

  /*
   * Normal main() thread activity, in this demo it does nothing except
   * sleeping in a loop and check the button state.
   */
  int counter = 0;
  while (1) {
    if (palReadLine(LINE_BUTTON) || palReadPad(GPIOG, GPIOG_PIN3)) {
      chprintf(chp, "exiting!!!\r\n\r\n");

      test_execute((BaseSequentialStream *)&SD3, &rt_test_suite);
      test_execute((BaseSequentialStream *)&SD3, &oslib_test_suite);
    }
    chThdSleepMilliseconds(1000);
    chprintf(chp, "printing counter: %d\r\n", counter);
    counter++;
  }
}

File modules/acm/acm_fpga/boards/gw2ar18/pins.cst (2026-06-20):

// 27 MHz system clock (bank 7)
IO_LOC  "HCLK" 4;
IO_PORT "HCLK" PULL_MODE=NONE;

// S1 reset button (active high; board has external 1k pull-down R6)
IO_LOC  "HRST" 88;
IO_PORT "HRST" IO_TYPE=LVCMOS33 PULL_MODE=NONE;

// fabric heartbeat UART TX, FPGA pin 73 (IOT40A)
IO_LOC  "UART_TX" 73;
IO_PORT "UART_TX" IO_TYPE=LVCMOS33 PULL_MODE=NONE DRIVE=8;

// 6 user leds (bank 6)
IO_LOC  "LED[5]" 20;
IO_PORT "LED[5]" IO_TYPE=LVCMOS33 PULL_MODE=NONE DRIVE=8;
IO_LOC  "LED[4]" 19;
IO_PORT "LED[4]" IO_TYPE=LVCMOS33 PULL_MODE=NONE DRIVE=8;
IO_LOC  "LED[3]" 18;
IO_PORT "LED[3]" IO_TYPE=LVCMOS33 PULL_MODE=NONE DRIVE=8;
IO_LOC  "LED[2]" 17;
IO_PORT "LED[2]" IO_TYPE=LVCMOS33 PULL_MODE=NONE DRIVE=8;
IO_LOC  "LED[1]" 16;
IO_PORT "LED[1]" IO_TYPE=LVCMOS33 PULL_MODE=NONE DRIVE=8;
IO_LOC  "LED[0]" 15;
IO_PORT "LED[0]" IO_TYPE=LVCMOS33 PULL_MODE=NONE DRIVE=8;

// ===========================================================================
// FMC multiplexed bus to the STM32 (16-bit AD + control), all LVCMOS33.
// AD is bidirectional; NADV/NOE/NWE/NE1 are inputs (pulled up so they idle
// deasserted before the STM32 brings FMC up); NWAIT is an output.
// fpga pin <-- jumper --> STM32 pin. run the bus slow for the breadboard PoC.
// ===========================================================================

// AD bus (16-bit: D0..D15)
IO_LOC  "FMC_AD[0]"  76;   // STM32 PD14
IO_PORT "FMC_AD[0]"  IO_TYPE=LVCMOS33 PULL_MODE=NONE;
IO_LOC  "FMC_AD[1]"  80;   // STM32 PD15
IO_PORT "FMC_AD[1]"  IO_TYPE=LVCMOS33 PULL_MODE=NONE;
IO_LOC  "FMC_AD[2]"  42;   // STM32 PD0
IO_PORT "FMC_AD[2]"  IO_TYPE=LVCMOS33 PULL_MODE=NONE;
IO_LOC  "FMC_AD[3]"  41;   // STM32 PD1
IO_PORT "FMC_AD[3]"  IO_TYPE=LVCMOS33 PULL_MODE=NONE;
IO_LOC  "FMC_AD[4]"  56;   // STM32 PE7
IO_PORT "FMC_AD[4]"  IO_TYPE=LVCMOS33 PULL_MODE=NONE;
IO_LOC  "FMC_AD[5]"  54;   // STM32 PE8
IO_PORT "FMC_AD[5]"  IO_TYPE=LVCMOS33 PULL_MODE=NONE;
IO_LOC  "FMC_AD[6]"  51;   // STM32 PE9
IO_PORT "FMC_AD[6]"  IO_TYPE=LVCMOS33 PULL_MODE=NONE;
IO_LOC  "FMC_AD[7]"  48;   // STM32 PE10
IO_PORT "FMC_AD[7]"  IO_TYPE=LVCMOS33 PULL_MODE=NONE;
IO_LOC  "FMC_AD[8]"  55;   // STM32 PE11
IO_PORT "FMC_AD[8]"  IO_TYPE=LVCMOS33 PULL_MODE=NONE;
IO_LOC  "FMC_AD[9]"  49;   // STM32 PE12
IO_PORT "FMC_AD[9]"  IO_TYPE=LVCMOS33 PULL_MODE=NONE;
IO_LOC  "FMC_AD[10]" 86;   // STM32 PE13
IO_PORT "FMC_AD[10]" IO_TYPE=LVCMOS33 PULL_MODE=NONE;
IO_LOC  "FMC_AD[11]" 79;   // STM32 PE14
IO_PORT "FMC_AD[11]" IO_TYPE=LVCMOS33 PULL_MODE=NONE;
IO_LOC  "FMC_AD[12]" 72;   // STM32 PE15
IO_PORT "FMC_AD[12]" IO_TYPE=LVCMOS33 PULL_MODE=NONE;
IO_LOC  "FMC_AD[13]" 71;   // STM32 PD8
IO_PORT "FMC_AD[13]" IO_TYPE=LVCMOS33 PULL_MODE=NONE;
IO_LOC  "FMC_AD[14]" 53;   // STM32 PD9 -- WAS BAD on 53/74/75, pick a clean pin
IO_PORT "FMC_AD[14]" IO_TYPE=LVCMOS33 PULL_MODE=NONE;
IO_LOC  "FMC_AD[15]" 52;   // STM32 PD10
IO_PORT "FMC_AD[15]" IO_TYPE=LVCMOS33 PULL_MODE=NONE;

// control
IO_LOC  "FMC_NADV"  31;    // STM32 PB7 (NL)
IO_PORT "FMC_NADV"  IO_TYPE=LVCMOS33 PULL_MODE=UP;
IO_LOC  "FMC_NOE"   26;    // STM32 PD4
IO_PORT "FMC_NOE"   IO_TYPE=LVCMOS33 PULL_MODE=UP;
IO_LOC  "FMC_NWE"   25;    // STM32 PD5
IO_PORT "FMC_NWE"   IO_TYPE=LVCMOS33 PULL_MODE=UP;
IO_LOC  "FMC_NE1"   29;    // STM32 PC7
IO_PORT "FMC_NE1"   IO_TYPE=LVCMOS33 PULL_MODE=UP;
IO_LOC  "FMC_NWAIT" 30;    // STM32 PC6
IO_PORT "FMC_NWAIT" IO_TYPE=LVCMOS33 PULL_MODE=NONE DRIVE=8;

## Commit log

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2025-06-12 updating the gameplane
    [signalmesh.kicad_pcb, signalmesh.kicad_sch]
2025-06-13 readme for modules
    [signalmesh.kicad_pcb, signalmesh.kicad_sch]
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2025-06-15 chibi semaphore example that seems to work decent. bit of noise tho on the circuit it seems
    [interrupt.c]
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2025-06-19 schematic updates
    [signalmesh.kicad_pcb, signalmesh.kicad_sch]
2025-06-20 update schematic and pcb. errors
    [signalmesh-B_Cu.gbr, signalmesh-B_Fab.gbr, signalmesh-B_Mask.gbr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]
2025-06-21 more schematic updates. semiworking PCB
    [freerouting.dsn, signalmesh.kicad_pcb, signalmesh.kicad_sch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]
2025-06-22 attempt at FMC interface
    [signalmesh.kicad_pcb]
2025-06-23 display driver schematic piece
    [signalmesh.kicad_pcb, signalmesh.kicad_sch]
2025-06-23 updating FMC pins
    [signalmesh.kicad_pcb, signalmesh.kicad_sch]
2025-06-24 UUM SPI flash. gpio ctrl with 74lvc
    [signalmesh.kicad_sch]
2025-06-24 add CAN tranceivers
    [signalmesh.kicad_sch]
2025-06-24 CAN rework
    [signalmesh.kicad_sch]
2025-06-24 PCB updates
    [signalmesh.kicad_pcb, signalmesh.kicad_sch]
2025-06-24 PCB update. CAN routing. making space. may need 4 layers!
    [signalmesh.kicad_pcb]
2025-06-25 attempting CAN routing. semi routed pcb
    [freerouting.dsn, signalmesh.kicad_pcb, signalmesh.kicad_sch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]
2025-06-25 all connections appear valid. some silkscreen clipping
    [freerouting.dsn, signalmesh.kicad_pcb, temp-freerouting.dsn]
2025-06-25 my CAN trscvr LAYOUT sucks
    [signalmesh.kicad_pcb]
2025-06-25 CAN pos neg lines routed. broke other shit. autoroute hates me
    [freerouting.dsn, signalmesh.kicad_pcb, temp-freerouting.dsn]
2025-06-26 routed no errors
    [freerouting.dsn, signalmesh.kicad_pcb, temp-freerouting.dsn]
2025-06-27 progress. might have enough of the vital stuff routed to get the autorouter working for the rest. not sure if it will follow rules though
    [signalmesh.kicad_pcb, signalmesh.kicad_sch]
2025-06-27 a bit of auto routing based on the literal stub traces I put in
    [signalmesh.kicad_pcb]
2025-06-27 ugh routing is a bit messy right now. need to go back to schematic and finish up wiring i forgot about primarily the UARTs for debugging on all boards and the cmd UART from AAM<->ACM
    [signalmesh.kicad_sch, signalmesh_3.kicad_pcb, signalmesh_revert2.kicad_pcb]
2025-06-28 good progress. build from here. bit of autorouter. not too shitty
    [BOM-signalmesh.csv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]
2025-06-28 i sort of like this. verifying one more time before printing
    [signalmesh.kicad_pcb]
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2025-06-29 adding v2 schematic. working with USB
    [BOM-signalmesh.csv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]
2025-06-29 i should really make this multiple sheets
    [signalmesh.kicad_sch, untitled.kicad_sch]
2025-06-29 removing the courtyard from the filler plots. theyre not actually components just an outline with throughholes
    [dsm.kicad_sch, signalmesh.kicad_pcb, signalmesh.kicad_sch]
2025-06-29 moving to multiple sheets for the schematic
    [AAM.kicad_sch, AAM_peripherals.kicad_sch, DSM.kicad_sch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]
2025-06-29 should probably write some code now
    [signalmesh.kicad_sch]
2025-06-30 adding more sheets in the schematic
    [7SDD.kicad_sch, AAM.kicad_sch, AAM_debug.kicad_sch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]
2025-07-03 progress on putting things in different sheets
    [7SDD.kicad_sch, AAM.kicad_sch, AAM_debug.kicad_sch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]
2025-07-04 v2 updates. remove sniffer
    [AAM.kicad_sch, AAM_debug.kicad_sch, AAM_midi.kicad_sch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]
2025-07-04 moving AAM -> APM. creatint some abstraction like stuff
    [AAM.kicad_sch, ACM.kicad_sch, ACM_debug.kicad_sch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]
2025-07-05 no errors in the ERC!
    [7SDD.kicad_sch, ACM.kicad_sch, ACM_debug.kicad_sch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]
2025-07-05 need to update PCB and new traces
    [DSM.kicad_sch, UUM.kicad_sch, UUM_debug.kicad_sch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]
2025-07-05 attempting new PCB layout
    [DSM.kicad_sch, signalmesh.kicad_pcb, signalmesh.kicad_sch]
2025-07-06 time to start routing?
    [ACM.kicad_sch, ACM_debug.kicad_sch, APM.kicad_sch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]
2025-07-07 gonna throw auto route on. I think I have enough put together for now
    [TDM.kicad_sch, signalmesh.kicad_pcb, signalmesh.kicad_sch]
2025-07-07 schematic updates, no errors at least. running DRC on pcb
    [7SDD.kicad_sch, APM_midi.kicad_sch, DSM.kicad_sch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]
2025-07-07 fixed designators
    [freerouting.dsn, signalmesh.kicad_pcb, signalmesh.kicad_sch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]
2025-07-07 routed with no errors. could probably do some more verification before sending the initial order of the v2 revamp then start designing out the AFFM module
    [freerouting.dsn, signalmesh.kicad_pcb, temp-freerouting.dsn]
2025-07-09 routed. saving the extra board in the same pcb file for when I want to creat the filter and fx module
    [BOM-signalmesh.csv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]
2025-07-12 attempting v2 spinout with jlcpcb
    [CPL-signalmesh.csv, signalmesh-CuBottom.gbr, signalmesh-CuIn1.gbr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]
2025-07-16 hmmm figuring out filter module right now
    [AFFM.kicad_sch, TDM.kicad_sch, signalmesh.kicad_pcb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]
2025-07-17 need to learn more about variable lpf, wiring, minimal capacitor for the circuit and cutoff with series resistor
    [AFFM.kicad_sch]
2025-07-19 schematic updates for affm
    [AFFM.kicad_sch]
2025-07-20 working on the new framework16
    [signalmesh.kicad_pcb]
2025-07-21 hmmm lpf, hpf, bpf, bsf all in there. I could probably make the board much smaller...
    [signalmesh.kicad_pcb]
2025-07-21 dip switch for multi pole filter? this is all for experimenting for now, a refined design with less togleables will come later
    [AFFM.kicad_sch, AFFM_filters.kicad_sch, USB_debug.kicad_sch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]
2025-07-21 dip switch symbol. how might this work...
    [AFFM_filters.kicad_sch]
2025-07-22 cool LPFs. i want to add some toggleability between my RC passive and active implementations...
    [7SDD.kicad_sch, ACM.kicad_sch, ACM_spiflash.kicad_sch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]
2025-07-27 some progress on affm board
    [AFFM.kicad_sch, AFFM_filters.kicad_sch, DSM.kicad_sch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]
2025-07-30 now making a v3 with HATs for each nucleo with my needed shit. this will make things very compact and hopefully much cheaper
    [7SDD.kicad_sch, ACM.kicad_sch, ACM_debug.kicad_sch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]
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2025-10-20 working pwm. not working on the servo tho
2025-10-20 servo code does something. the top claw on the arm is too tight, not enough torque on the thing but maybe it needs more power...?
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2025-12-08 diagnosing i2c failures. i can only imagine the pain this will be for SPI and CAN...
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2026-01-25 using gowin ide and some other stuff
    [device.cfg]
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2026-06-20 stm FMC clock issue maybe? can see LEDs blink in memapped mode with gdb but not FW
    [bsp_spi_config.c, pins.cst]
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2026-06-27 lots of working stuff mostly cheby and FMC + wishbone 16 bit bus related. ran into weird regression that is actually a flaky wiring issue on my end
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
